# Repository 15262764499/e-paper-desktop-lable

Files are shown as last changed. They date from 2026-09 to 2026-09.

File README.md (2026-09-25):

# 四色墨水屏桌面信息终端

基于 STM32G070CBT6 与 4.2 英寸 400 × 300 四色墨水屏的桌面终端。设备通过 NFC 识别与配对，通过 BLE 接收手机或电脑制作的画面；也可以显示带本地时钟和环境信息的日历，并用七颗 LED 呈现灯效。仓库提供设备固件、Bootloader、硬件资料、3D 外壳模型及客户端对接文档。

> 本仓库目前主要是设备端工程和协议资料。Android 与 Windows 应用的源码、安装包及各自的构建说明未包含在当前仓库中；下文“二次开发”列出的是开发这两端应用时需要阅读的设备协议与需求文档。部分文档保留早期设计草案和历史验证记录，遇到不一致时请结合当前固件接口核对。

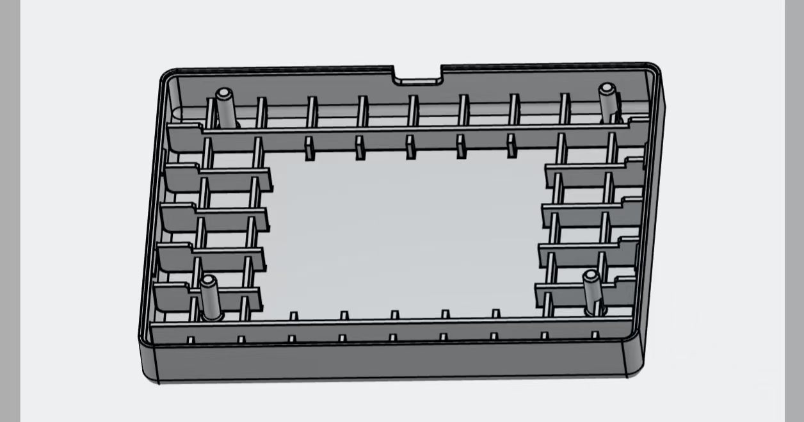
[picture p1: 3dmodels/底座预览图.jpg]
底座预览

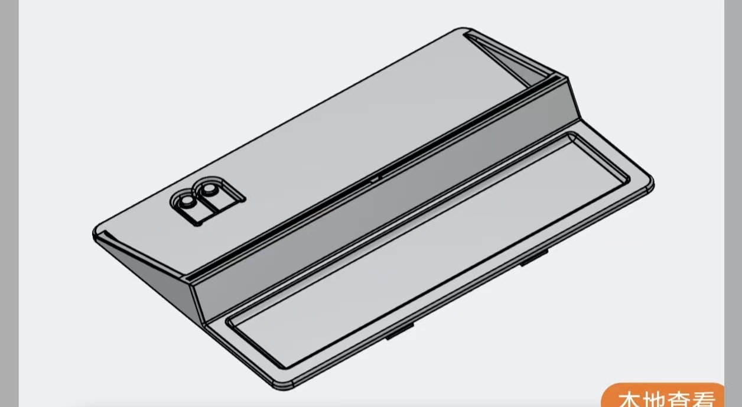
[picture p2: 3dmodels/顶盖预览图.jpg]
顶盖预览


## 能做什么

- **四色图片显示**：客户端将照片裁剪并缩放到 400 × 300，量化为黑、白、黄、红四种颜色，编码为 30,000 字节的 2bpp 画面，经 BLE 分包发送；设备完成校验后刷新。墨水屏断电仍能保持最后画面。
- **NFC 配对与 BLE 通信**：手机通过 ST25DV04K 的 NDEF 信息取得设备身份与配对凭据，再连接 CH9140；图片、控制命令和升级数据经 BLE 传送，NFC 不承担图片传输。
- **日历与温湿度**：客户端制作日历底图，STM32 使用 RTC 和 AHT20 叠加日期、今日高亮及室内温度；保存的底图支持设备在跨日后本地重绘。Android 日历方案还包含系统日历事件、手机定位与室外天气。
- **七灯效果**：74HC595 驱动七颗 LED，提供关闭、湿度呼吸、由中心向两侧展开的扩散呼吸三种模式；NFC 感应时临时显示同步呼吸。按键和经过认证的 BLE 命令可选择背景模式。
- **BLE 固件升级**：Bootloader 接收 .epota 升级包，校验后更新 Application；中断升级时可以重新进入恢复传输流程。
- **电脑串口灯效**：设备经 CH340 的 USART1 接收 Pulse v1 控制协议，可将电脑端的负载数据映射为 LED 效果。该路径与通过 CH9140 使用 BLE 发送画面的路径不同。

## 硬件与通信

| 模块 | 用途 |
| --- | --- |
| STM32G070CBT6 | 固件运行、墨水屏刷新、RTC、协议处理和灯效控制 |
| GDEM042F86，400 × 300 四色墨水屏 | 图片与日历显示 |
| ST25DV04K | NFC 近场识别与配对信息 |
| CH9140 | BLE 透明串口，连接 MCU 的 USART2 |
| AHT20 | 室内温湿度采样 |
| 74HC595、七颗 LED | 氛围灯输出 |
| CH340 | 电脑与 MCU 的 USART1 串口通信 |

具体接线请看 [电路图](refer_doc/SCH_Schematic3_2026-09-11.pdf) 与 [CubeMX 配置](refer_doc/墨水屏项目.ioc)。三维模型和预览图位于 [3dmodels](3d外壳)；立创 EDA 工程位于 [pcbproject](pcbproject)。

## 仓库导航

```text
Core/          STM32 Application：屏幕、传图、RTC、日历、传感器、灯效和串口协议
Bootloader/    BLE OTA Bootloader
Drivers/       STM32 HAL / CMSIS 依赖
files/         硬件、Android 需求和设备通信协议文档
docs/          Windows 固件构建说明及 Pulse 开发记录
3d外壳/        外壳 STEP 模型、Blender 文件与预览图
pcbproject/    PCB 工程
tools/         OTA 打包等辅助工具
tests/         设备端协议和灯效测试
```

## 二次开发：先读哪些文档

### Android 应用

建议按以下顺序阅读。文档路径均在 files/ 内：

1. [ANDROID_APP_REQUIREMENTS.md](refer_doc/ANDROID_APP_REQUIREMENTS.md)：应用流程、NFC 唤起、BLE GATT、认证、图片处理、传输状态与错误处理的总入口。
2. [IMAGE_TRANSFER_PROTOCOL.md](refer_doc/IMAGE_TRANSFER_PROTOCOL.md)：NDEF 格式、BLE 帧、HELLO/认证、2bpp 数据、分包 ACK、CRC/HMAC 和状态码。客户端与固件联调以此为基础。
3. [ANDROID_CALENDAR_DEVELOPMENT.md](refer_doc/ANDROID_CALENDAR_DEVELOPMENT.md)：若开发日历功能，阅读日历底图与 MCU 叠加层的分工、系统日历、天气、时间同步和画布坐标。文档含早期草案描述，实际支持情况还需与当前固件核对。
4. [ANDROID_LED_CONTROL.md](refer_doc/ANDROID_LED_CONTROL.md)：若开发七灯控制或动画预览，阅读三种模式、颜色、BLE 命令与 NFC 临时效果的优先级。
5. [BLE_OTA_DESIGN.md](refer_doc/BLE_OTA_DESIGN.md)：若开发手机端固件升级，阅读进入 Bootloader、重新连接、.epota 包结构、升级分片和恢复流程。

### Windows / 电脑端应用

电脑端涉及两条通信路径，先确定要开发哪一项：

| 功能 | files/ 中应读的文档 | 还应核对 |
| --- | --- | --- |
| BLE 传图与设备控制 | [IMAGE_TRANSFER_PROTOCOL.md](refer_doc/IMAGE_TRANSFER_PROTOCOL.md)；日历功能参考 [ANDROID_CALENDAR_DEVELOPMENT.md](refer_doc/ANDROID_CALENDAR_DEVELOPMENT.md)，灯效参考 [ANDROID_LED_CONTROL.md](refer_doc/ANDROID_LED_CONTROL.md) | Android 专属的 NFC 唤起、系统日历、定位和权限部分需要替换为 Windows 实现；电脑端同样要满足设备认证与报文格式 |
| BLE 固件升级 | [BLE_OTA_DESIGN.md](refer_doc/BLE_OTA_DESIGN.md) 和 [IMAGE_TRANSFER_PROTOCOL.md](refer_doc/IMAGE_TRANSFER_PROTOCOL.md) | BLE 断开重连、升级清单与 ACK/状态处理 |
| CH340 串口 Pulse 灯效 | files/ 内无独立的 Pulse 协议文档；LED 背景逻辑可读 [LED_LOGIC.md](refer_doc/LED_LOGIC.md) | [MCU_BUILD_WINDOWS.md](refer_doc/MCU_BUILD_WINDOWS.md)、[Pulse Windows 设计记录](refer_doc/superpowers/plans/2026-09-16-pulse-windows.md)、`Core/Inc/pulse_protocol.h`、`Core/Src/pulse_protocol.c`、`Core/Src/pulse_uart.c` |

### 设备固件、硬件与外壳

- 修改设备端协议或屏幕驱动：先读 [图片传输协议](refer_doc/IMAGE_TRANSFER_PROTOCOL.md)，再看 `Core/Src/image_transfer.c`、`Core/Src/gdem042f86.c`。
- 修改 OTA：先读 [OTA 设计]（refer_doc/BLE_OTA_DESIGN.md)，再看 `Bootloader/` 和 `tools/package_ota.py`。
- 修改灯效、按键或传感器：阅读 [LED_LOGIC.md](refer_doc/LED_LOGIC.md) 和 [ANDROID_LED_CONTROL.md](files/ANDROID_LED_CONTROL.md)，再看 `Core/Src/led_595.c`、`Core/Src/aht20.c`。
- 修改硬件与外壳：参考 [原理图](refer_doc/SCH_Schematic3_2026-09-11.pdf)、[IOC](files/墨水屏项目.ioc)、[PCB 工程](pcbproject) 和 [外壳模型](3d外壳)。[HARDWARE_2026_09_11.md](refer_doc/HARDWARE_2026_09_11.md) 是历史适配记录，其中早期同步呼吸演示已由当前三模式逻辑替代。

## 编译与烧录设备固件

在具备 Arm GNU Toolchain 与 Make 的环境中，从仓库根目录编译：

```bash
make -j4 firmware
```

Windows PowerShell 可使用仓库内脚本；工具链安装与定位方法见 [Windows 构建说明](refer_doc/MCU_BUILD_WINDOWS.md)：

```powershell
powershell -NoProfile -ExecutionPolicy Bypass -File .\build-mcu.ps1
```

| 组件 | 输出 HEX | BIN 烧录起始地址 |
| --- | --- | --- |
| Bootloader | `build_bootloader/epaper_bootloader.hex` | `0x08000000` |
| Application | `build/epaper_project.hex` | `0x08006000` |

HEX 自带目标地址；首次在空白芯片上使用时需分别写入 Bootloader 和 Application。Application 的 BIN 不能烧到 `0x08000000`。已有设备更新前请先阅读 [OTA 布局与恢复说明](refer_doc/BLE_OTA_DESIGN.md)，避免误擦 Bootloader、日历底图或 OTA 元数据。

## 协议与数据提示

- BLE 传图使用 `FFF0` 服务、`FFF1` Notify、`FFF2` Write；底层串口为 115200、8N1。图片画面固定 400 × 300、2bpp、30,000 字节；图片传输需要逐块确认并在校验完成后等待屏幕刷新。
- NFC 配对数据包含设备标识与密钥信息。不要在日志、演示截图或 issue 中公开真实设备的配对凭据。
- 仓库中的 OTA 发布密钥仅供开发测试；若用于实际交付设备，应替换并妥善保管发布凭据。具体限制见 [OTA 安全边界](refer_doc/BLE_OTA_DESIGN.md)。

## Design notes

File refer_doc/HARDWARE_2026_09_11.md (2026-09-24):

# 2026-09-11 硬件适配与呼吸灯测试

> 以下为 2026-09-11 历史硬件演示记录。当前三模式驱动、接口和时序以 [LED_LOGIC.md](LED_LOGIC.md) 与 [ANDROID_LED_CONTROL.md](ANDROID_LED_CONTROL.md) 为准；旧 SetMask/共用 OE PWM 演示已替换。

固件按 `SCH_Schematic3_2026-09-11.pdf` 接线适配。

| MCU 引脚 | 功能 | 74HC595 引脚 |
| --- | --- | --- |
| PA4 / AF1 | SPI2_MOSI | DS，14 脚 |
| PA0 / AF0 | SPI2_SCK | SHCP，11 脚 |
| PB14 / GPIO | 锁存脉冲 | STCP，12 脚 |
| PA8 / AF2 | TIM1_CH1，低有效 PWM | OE#，13 脚 |

SPI2 使用模式 0、MSB 优先、8 位、单线发送；当前 16 MHz 时钟下速率为 500 kbit/s。引脚复用依据 [ST 数据手册表 12](https://www.st.com/resource/en/datasheet/stm32g070cb.pdf)。MR# 由图中的 R70 上拉。

图中实际是 Q1～Q7 接 7 颗 LED，Q0（15 脚）未连接；Q7S 是级联输出，不是第八路灯。LED 阳极通过 1 kΩ 接 3V3_SYS，阴极接 Q 输出，因此输出低电平点亮。初始化移入 `0x01`，让 Q1～Q7 有效、Q0 关闭。

上电进入循环同步呼吸：1.5 秒渐亮、1.5 秒渐暗。PWM 为 1 kHz，亮度每 10 ms 更新，使用平方曲线改善暗部变化。SysTick 只计算亮度并写 CCR1，不进行 SPI 传输或延时；正常中断开启时，墨水屏阻塞等待不会停止呼吸。Flash 擦写或关闭中断仍可能使亮度更新短暂停顿。

`Core/Inc/led_595.h` 中的 `LED595_BREATH_PERIOD_MS` 可修改周期，`LED595_DEMO_MASK` 可选择输出。掩码的 bit0～bit7 对应 Q0～Q7，1 表示选中；若以后补接 Q0 的 LED，可改为 `0xFF`。`LED595_SetMask()` 应从主循环调用，支持后续流水灯效果；当前演示为同步呼吸。

NFC、BLE、AHT20 与 I2C 上拉均按直供电处理，代码不再配置 PB9、PB10、PB5 为电源使能。NFC 直接探测 I2C 地址，不再切换电源极性。BLE 使用 PB15：`Bluetooth_Sleep()` 拉低 SLP，`Bluetooth_Wake()` 拉高并等待 500 ms。休眠前需结束 BLE 收发；当前传图程序默认唤醒，不自动空闲休眠，以便手机继续连接。独立墨水屏诊断演示中的原断电操作已改为 SLP 休眠。Bootloader 在 OTA 期间保持 BLE 唤醒，并把 PA8 拉高关闭灯输出。

构建：`make -j4 firmware`。

本次应用和 Bootloader 已编译、链接成功，Flash 的 text+data 分别为 36224 B / 72 KiB 和 11160 B / 24 KiB。链接器报告了 newlib 的 `_read/_write/_close/_lseek` 占位实现以及 RWX LOAD 段警告；本次未调整系统调用或链接脚本。尚未烧录或进行实物测试。

- 应用：`build/epaper_project.hex`；BIN 加载地址为 `0x08006000`。
- Bootloader：`build_bootloader/epaper_bootloader.hex`；BIN 加载地址为 `0x08000000`。
- HEX 自带地址。应用依赖本项目 Bootloader，不应将应用 BIN 写到 Flash 起始地址。

`files/墨水屏项目.ioc` 已同步删除旧电源引脚并加入 SPI2/TIM1/PB14 配置。呼吸灯逻辑和初始化由 `led_595.c` 管理；本次没有运行 CubeMX 重新生成工程。以后重新生成时需保留 `LED595_Init()`、SysTick 中的 `LED595_Tick()` 和 Makefile 源文件项。

板上检查：上电观察 7 颗灯同步呼吸；示波器检查 PA0 的 8 个时钟及其后的 PB14 锁存上升沿，PA8 应为低有效 1 kHz PWM。随后验证手机连接、NFC 配对、传图和 OTA。编译与静态检查无法代替上述实物验证。

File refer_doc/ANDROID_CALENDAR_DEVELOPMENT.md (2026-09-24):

# 安卓端日历功能开发说明

版本：0.1（联调草案）  
目标硬件：STM32G070CBT6 + CH9140 + ST25DV04K + AHT20 + GDEM042F86 400×300 四色墨水屏  
依赖协议：[IMAGE_TRANSFER_PROTOCOL.md](IMAGE_TRANSFER_PROTOCOL.md)

## 1. 目标

安卓应用在用户触碰 NFC 后完成以下流程：

1. 读取 NFC 配对信息并连接 CH9140 BLE。
2. 与 STM32 完成 `HELLO/AUTH` 身份认证。
3. 接收 STM32 上传的 AHT20 室内温湿度。
4. 使用手机时间校准 STM32 RTC。
5. 读取 Android 系统日历中今天的日程事件。
6. 申请前台定位权限，获取手机当前位置，并通过项目默认天气提供商 Open-Meteo 获取室外天气。
7. 绘制 400×300 日历基础画面，包括日历框、星期标题、天气和今日日程。
8. 将基础画面量化、打包并通过现有安全图片协议发送。
9. STM32 在基础画面上叠加日期数字、当前日期、室内温度和今日高亮框，再刷新墨水屏。
10. 手机不再连接时，STM32 依靠 RTC 在跨日后重新绘制日期、室内温度和高亮框。

本文中的“今日任务”默认指 Android `Calendar Provider` 中的日历事件，不包括 Google Tasks、Microsoft To Do 等独立待办服务。若产品需要真正的待办事项，需要另外接入对应账号和网络 API。

## 2. 两端职责

| 内容 | 安卓端 | STM32端 |
|---|---|---|
| 400×300基础画面 | 生成并发送 | 接收并保存日历模板 |
| 固定日历框 | 绘制 | 不绘制 |
| 星期标题 | 绘制 | 不绘制 |
| 室外天气和图标 | 获取、绘制 | 不解析天气 |
| 今日系统日历事件 | 读取、排版、绘制 | 不保存事件文本 |
| 月份日期数字1～31 | 预览时模拟，传输画面中留白 | 根据RTC绘制 |
| 当前年月日 | 预览时模拟，传输画面中留白 | 根据RTC绘制 |
| 今日高亮框 | 预览时模拟，传输画面中留白 | 根据RTC绘制 |
| 室内温度 | 用于最终预览 | 从AHT20读取并绘制 |
| 时间维护和跨日 | 发送校时数据 | RTC维护并在零点刷新 |

安卓发送的是“基础模板”，不是最终画面。安卓预览必须在基础模板的副本上模拟 STM32 叠加层，不能把叠加层写进实际发送的30,000字节，否则会出现日期和高亮重复。

## 3. 必须解决的模板保存问题

当前固件把图片直接写入墨水屏控制器RAM，不在STM32中保存。屏幕断电后，STM32第二天无法重新得到安卓绘制的天气和任务底图。

日历模式需要嵌入式端新增一个保留Flash区域：

- 建议保留最后32KB内部Flash。
- 保存30,000字节安卓日历基础模板及少量元数据。
- 普通照片仍然不保存。
- 模板只有在长度、CRC32和HMAC全部验证成功后才标记为有效。
- 收到相同CRC的模板时不重复擦写Flash。
- 固件升级可以擦除模板；升级后等待用户再次碰NFC生成即可。

当前固件约使用25KB Flash，STM32总Flash为128KB，预留32KB模板区后仍有明显余量。链接脚本必须缩小应用Flash长度，避免程序覆盖模板区。

如果不增加模板存储，STM32只能在手机连接当天叠加字符，无法在第二天保留安卓绘制的天气和任务区域后再进行完整刷新。

## 4. 固定画布和布局版本

所有绘图使用固定的400×300逻辑像素，不使用Android的`dp`、屏幕密度或自动缩放。

布局版本：`CALENDAR_LAYOUT_V1 = 1`

### 4.1 区域定义

| 区域 | 坐标 | 所有者 | 内容 |
|---|---|---|---|
| 日期标题 | `x=0..175, y=0..47` | STM32 | `2026年8月20日`等 |
| 室内温度 | `x=176..279, y=0..47` | STM32 | `室内 25.6℃` |
| 星期标题 | `x=0..279, y=48..71` | 安卓 | 一、二、三、四、五、六、日 |
| 月历网格 | `x=0..279, y=72..299` | 安卓+STM32 | 安卓画线；STM32画日期和高亮 |
| 室外天气 | `x=280..399, y=0..115` | 安卓 | 天气、室外温度、天气图标 |
| 今日日程 | `x=280..399, y=116..299` | 安卓 | 系统日历事件 |

屏幕右侧和左侧之间在 `x=279` 处绘制黑色分隔线。

### 4.2 月历网格

- 月历宽度280像素，每列40像素。
- 星期标题高度24像素。
- 日期区固定6行，每行38像素。
- 竖线位置：`0, 40, 80, 120, 160, 200, 240, 279`。
- 横线位置：`48, 72, 110, 148, 186, 224, 262, 299`。
- STM32根据当月1日星期和当月天数确定每个日期所在单元格。
- STM32将日期数字放在单元格左上角，建议偏移 `(4, 3)`。
- 今日高亮框在单元格边界内缩2像素，建议使用红色2像素描边。
- 周六、周日日期可以使用红色，工作日使用黑色。

### 4.3 安卓必须留白的区域

基础模板中以下位置必须保持纯白色 `#FFFFFF`，不能绘制文字、图标或抖动噪声：

- 日期标题区域内部。
- 室内温度区域内部。
- 所有日期单元格内部，网格线除外。
- 今日高亮框可能经过的单元格内缩0～4像素区域。

否则STM32叠加字符时无法可靠清除旧日期和旧高亮框。

## 5. NFC、BLE和传输流程

```text
NFC碰一碰
  -> BLE扫描和连接
  -> 订阅FFF1
  -> HELLO_REQ / HELLO_RSP
  -> AUTH_PROVE
  -> SENSOR_RSP（室内温湿度）
  -> TIME_SYNC（新增）
  -> 查询今天的系统日历
  -> 获取或读取缓存天气
  -> 生成日历基础模板和最终预览
  -> IMAGE_BEGIN（日历模式）
  -> IMAGE_DATA
  -> IMAGE_END
  -> 等待COMPLETE
```

传输仍沿用现有分包、CRC32、ACK、重试和图片HMAC规则。日历模板仍然必须恰好是30,000字节。

## 6. 协议扩展要求

本节需要安卓和固件同步实现；当前固件尚未支持这些扩展。

### 6.1 能力声明

建议在`HELLO_RSP`末尾增加两字节`capabilities`：

```text
bit0 = 支持日历基础模板
bit1 = 支持TIME_SYNC
bit2 = 支持RTC自动跨日刷新
bit3 = 支持内部Flash模板保存
```

安卓只有在必要能力全部存在时才显示“发送日历”。旧固件仍可继续使用普通照片模式。

### 6.2 TIME_SYNC

建议新增：

```text
TIME_SYNC = 0x04
```

payload：

| 偏移 | 长度 | 内容 |
|---:|---:|---|
| 0 | 8 | Unix epoch seconds，u64小端 |
| 8 | 2 | 当前UTC偏移分钟数，i16小端；中国为480 |
| 10 | 16 | timeTag |

认证标签：

```text
timeTag = first16(HMAC-SHA256(
  sessionKey,
  ASCII("EPD-TIME-V1") ||
  sequenceLE16 || epochSecondsLE64 || utcOffsetMinutesLE16
))
```

STM32验证成功后设置RTC并返回普通`ACK`。安卓应在生成日历前发送校时，设备拒绝校时时不得发送日历模板。

### 6.3 日历渲染配置

现有`IMAGE_BEGIN`偏移9的`reserved`改为`renderProfile`：

```text
0x00 = 普通图片，不叠加、不保存
0x11 = 日历布局V1，叠加日期/室内温度/高亮并保存模板
```

普通图片继续使用原有`EPD-IMAGE-V1`标签。日历模式使用独立域，防止渲染配置被未授权修改：

```text
calendarTag = first16(HMAC-SHA256(
  sessionKey,
  ASCII("EPD-CALENDAR-V1") ||
  imageIdLE32 || sizeLE32 || imageCrcLE32 ||
  renderProfile || frameBytes
))
```

`IMAGE_END`结构可以保持不变，但日历模式下最后16字节应填`calendarTag`。

## 7. AHT20室内温湿度

当前协议已经定义：

```text
SENSOR_REQ = 0x03
SENSOR_RSP = 0x84
```

认证成功后STM32会主动发送一次`SENSOR_RSP`。安卓需要验证传感器HMAC后再使用数据。

应用数据模型：

```kotlin
data class IndoorReading(
    val temperatureCentiC: Int,
    val humidityCentiPercent: UInt,
    val receivedAt: Instant,
    val valid: Boolean,
)
```

显示格式：

- 室内温度保留一位小数，例如`25.6℃`。
- 湿度本版本不由STM32叠加，可以保留在安卓预览或以后扩展。
- `SENSOR_RSP`失败时，最终预览显示`室内 --.-℃`。
- STM32本地跨日刷新时重新读取AHT20，使用最新温度，不依赖安卓预览值。
- 日历模式下STM32每5分钟重新读取一次AHT20，并在顶部同时显示室内温度和湿度；该周期刷新不会在普通照片模式下执行。

## 8. 读取Android系统日历

Android官方`Calendar Provider`通过`CalendarContract`提供日历事件。读取需要危险权限`READ_CALENDAR`；只读取事件不需要`WRITE_CALENDAR`。

官方参考：

- [Calendar Provider概览](https://developer.android.com/identity/providers/calendar-provider)
- [CalendarContract.Instances](https://developer.android.com/reference/android/provider/CalendarContract.Instances)
- [READ_CALENDAR权限](https://developer.android.com/reference/android/Manifest.permission#READ_CALENDAR)

### 8.1 Manifest

```xml
<uses-permission android:name="android.permission.READ_CALENDAR" />
```

运行时使用`ActivityResultContracts.RequestPermission()`申请。用户拒绝后仍允许生成日历，只在任务区域显示“未授权读取日历”，不要重复强制弹窗。

### 8.2 为什么查询Instances

应查询`CalendarContract.Instances`，不要直接只查`Events`：

- `Instances`会展开重复事件的每一次发生记录。
- 可以正确得到今天实际发生的实例。
- 查询URI必须附加开始和结束毫秒时间戳。

### 8.3 今天的时间窗口

必须根据手机当前时区计算本地自然日，不能简单使用`now ± 24小时`：

```kotlin
val zone = ZoneId.systemDefault()
val today = LocalDate.now(zone)
val beginMillis = today
    .atStartOfDay(zone)
    .toInstant()
    .toEpochMilli()
val endMillis = today
    .plusDays(1)
    .atStartOfDay(zone)
    .toInstant()
    .toEpochMilli()
```

### 8.4 查询示例

```kotlin
data class TodayEvent(
    val eventId: Long,
    val title: String,
    val beginMillis: Long,
    val endMillis: Long,
    val allDay: Boolean,
    val location: String?,
)

fun queryTodayEvents(
    resolver: ContentResolver,
    beginMillis: Long,
    endMillis: Long,
): List<TodayEvent> {
    val uriBuilder = CalendarContract.Instances.CONTENT_URI.buildUpon()
    ContentUris.appendId(uriBuilder, beginMillis)
    ContentUris.appendId(uriBuilder, endMillis)

    val projection = arrayOf(
        CalendarContract.Instances.EVENT_ID,
        CalendarContract.Instances.TITLE,
        CalendarContract.Instances.BEGIN,
        CalendarContract.Instances.END,
        CalendarContract.Instances.ALL_DAY,
        CalendarContract.Instances.EVENT_LOCATION,
        CalendarContract.Instances.STATUS,
    )

    val result = mutableListOf<TodayEvent>()
    resolver.query(
        uriBuilder.build(),
        projection,
        null,
        null,
        "${CalendarContract.Instances.BEGIN} ASC",
    )?.use { cursor ->
        val eventIdIndex = cursor.getColumnIndexOrThrow(
            CalendarContract.Instances.EVENT_ID)
        val titleIndex = cursor.getColumnIndexOrThrow(
            CalendarContract.Instances.TITLE)
        val beginIndex = cursor.getColumnIndexOrThrow(
            CalendarContract.Instances.BEGIN)
        val endIndex = cursor.getColumnIndexOrThrow(
            CalendarContract.Instances.END)
        val allDayIndex = cursor.getColumnIndexOrThrow(
            CalendarContract.Instances.ALL_DAY)
        val locationIndex = cursor.getColumnIndexOrThrow(
            CalendarContract.Instances.EVENT_LOCATION)
        val statusIndex = cursor.getColumnIndexOrThrow(
            CalendarContract.Instances.STATUS)

        while (cursor.moveToNext()) {
            if (cursor.getInt(statusIndex) ==
                CalendarContract.Events.STATUS_CANCELED) {
                continue
            }

            result += TodayEvent(
                eventId = cursor.getLong(eventIdIndex),
                title = cursor.getString(titleIndex)
                    ?.trim()
                    ?.takeIf { it.isNotEmpty() }
                    ?: "未命名日程",
                beginMillis = cursor.getLong(beginIndex),
                endMillis = cursor.getLong(endIndex),
                allDay = cursor.getInt(allDayIndex) != 0,
                location = cursor.getString(locationIndex)
                    ?.trim()
                    ?.takeIf { it.isNotEmpty() },
            )
        }
    }
    return result
}
```

实际调用前必须再次检查`READ_CALENDAR`权限，并在`Dispatchers.IO`执行查询。

### 8.5 任务排版规则

- 标题固定为“今日日程”。
- 全天事件显示`全天 标题`。
- 普通事件显示`HH:mm 标题`。
- 按开始时间升序排列。
- 最多显示5条。
- 标题最多两行，超出区域使用省略号。
- 超过5条时，最后一行显示`另有 N 项`。
- 不显示事件描述、参会人、会议链接和账号邮箱。
- 日志中不得输出事件标题和地点。

## 9. 跨日后的任务和天气过期

STM32能够自主更新日期和室内温度，但安卓绘制的任务和天气不会自动变化。

日历模板元数据至少保存：

```text
templateLocalDate
weatherValidUntilEpoch
templateCrc32
layoutVersion
```

推荐降级规则：

- RTC日期仍等于`templateLocalDate`：正常显示任务。
- RTC日期已经变化：STM32在重新流式输出模板时将任务区域覆盖为白色，并显示红色`SYNC`提示。
- 天气超过`weatherValidUntilEpoch`：将天气区域覆盖为白色并显示`SYNC`。
- 用户再次碰NFC后，安卓重新读取当天事件和天气并发送新模板。

如果希望跨日后仍显示正确任务，协议必须改为安卓发送未来多天的结构化事件，由STM32负责文字排版；这不属于本版本范围。

## 10. 定位和天气数据要求

Android系统没有统一的“系统默认天气服务”API。本项目指定
[Open-Meteo Forecast API](https://open-meteo.com/en/docs)作为默认天气提供商，
但仍通过接口隔离，方便以后替换服务商。

天气只在用户通过NFC进入日历生成流程、应用处于前台时获取一次位置，不持续跟踪，也不申请后台定位权限。城市级天气不要求GPS级精度；用户只授予近似位置时也必须正常工作。

### 10.1 Manifest权限

```xml
<uses-permission android:name="android.permission.INTERNET" />
<uses-permission android:name="android.permission.ACCESS_COARSE_LOCATION" />
<uses-permission android:name="android.permission.ACCESS_FINE_LOCATION" />
```

不要声明：

```xml
<uses-permission android:name="android.permission.ACCESS_BACKGROUND_LOCATION" />
```

Android 12及以上允许用户只授予近似位置。若应用请求精确位置，必须把`ACCESS_FINE_LOCATION`和`ACCESS_COARSE_LOCATION`放在同一次运行时请求中；应用不能把“仅授予近似位置”视为错误。参考Android官方的[运行时定位权限说明](https://developer.android.com/develop/sensors-and-location/location/permissions/runtime)。

```kotlin
val locationPermissionLauncher = registerForActivityResult(
    ActivityResultContracts.RequestMultiplePermissions()
) { result ->
    when {
        result[Manifest.permission.ACCESS_FINE_LOCATION] == true -> {
            loadWeather(LocationAccuracy.PRECISE)
        }
        result[Manifest.permission.ACCESS_COARSE_LOCATION] == true -> {
            loadWeather(LocationAccuracy.APPROXIMATE)
        }
        else -> {
            loadCachedWeatherOrUnavailable()
        }
    }
}

locationPermissionLauncher.launch(
    arrayOf(
        Manifest.permission.ACCESS_FINE_LOCATION,
        Manifest.permission.ACCESS_COARSE_LOCATION,
    )
)
```

权限应在用户点击“生成日历”或NFC识别成功后、界面说明天气需要当前位置时申请，不能在应用无上下文启动时直接弹出。

### 10.2 获取一次当前位置

推荐使用Google Play services的`FusedLocationProviderClient`：

```kotlin
interface DeviceLocationRepository {
    suspend fun getCurrentLocation(): Result<DeviceLocation>
}

data class DeviceLocation(
    val latitude: Double,
    val longitude: Double,
    val accuracyMeters: Float?,
    val capturedAt: Instant,
)
```

获取策略：

1. 权限已经授予后调用`getCurrentLocation()`请求一次新位置。
2. 使用平衡功耗精度，天气不要求高精度GPS。
3. 新位置超时或返回`null`时尝试`lastLocation`。
4. 最近位置不得早于6小时；超过6小时视为不可用。
5. 定位完成后不注册持续位置更新。
6. 系统定位关闭时提示用户打开定位，或者使用天气缓存。

Android官方建议需要较新鲜的位置时优先使用`getCurrentLocation()`，而`lastLocation`速度快但可能过期：[获取当前位置](https://developer.android.com/develop/sensors-and-location/location/retrieve-current)。

### 10.3 Open-Meteo请求

默认请求：

```text
GET https://api.open-meteo.com/v1/forecast
  ?latitude={latitude}
  &longitude={longitude}
  &current=temperature_2m,weather_code
  &daily=temperature_2m_max,temperature_2m_min,precipitation_probability_max
  &timezone=auto
  &forecast_days=2
```

应用只需要当前天气和当天预报：

- `current.temperature_2m`：室外当前温度。
- `current.weather_code`：WMO天气代码，用于选择四色图标和中文描述。
- `daily.temperature_2m_min[0]`：当天最低温。
- `daily.temperature_2m_max[0]`：当天最高温。
- `daily.precipitation_probability_max[0]`：当天最大降水概率。
- `timezone=auto`：让天气结果使用坐标对应时区。

经纬度发送前建议四舍五入到小数点后两位，约为公里级精度，足以查询天气并减少不必要的位置精度暴露。

### 10.4 数据接口

```kotlin
data class WeatherSnapshot(
    val conditionText: String,
    val currentCentiC: Int,
    val lowCentiC: Int?,
    val highCentiC: Int?,
    val precipitationPercent: Int?,
    val icon: WeatherIcon,
    val observedAt: Instant,
    val validUntil: Instant,
)

interface WeatherRepository {
    suspend fun getWeather(
        location: DeviceLocation,
        forceRefresh: Boolean,
    ): Result<WeatherSnapshot>
}
```

要求：

- 默认使用Open-Meteo，不在UI中要求用户选择天气提供商。
- 必须同时支持精确位置和近似位置授权结果。
- 不申请后台定位，应用离开前台后不继续更新位置。
- API失败时优先使用未过期缓存。
- 没有可用缓存时显示“天气不可用”，仍允许发送日历。
- Open-Meteo服务条款、请求额度和商业使用条件需要在发布前复核；接口层必须允许以后切换自建代理或其他提供商。
- 明确区分“室外”天气温度和AHT20“室内”温度。
- 日志、崩溃报告和分析平台不得记录原始经纬度。

## 11. 安卓绘图实现

使用`Bitmap + Canvas + Paint`生成固定像素画面：

```kotlin
val bitmap = Bitmap.createBitmap(
    400,
    300,
    Bitmap.Config.ARGB_8888,
)
val canvas = Canvas(bitmap)
canvas.drawColor(Color.WHITE)
```

Android官方`Canvas`支持绘制文字、直线、矩形和Bitmap：
[Canvas API](https://developer.android.com/reference/android/graphics/Canvas)。

建议拆分：

```text
CalendarBaseRenderer
  drawGrid()
  drawWeekdayHeader()
  drawWeather()
  drawTodayEvents()
  drawSyncTimestamp()

CalendarPreviewOverlayRenderer
  drawDateNumbers()
  drawCurrentDateHeader()
  drawIndoorTemperature()
  drawTodayHighlight()
```

`CalendarBaseRenderer`的输出参与CRC/HMAC并发送；`CalendarPreviewOverlayRenderer`只作用于预览副本。

### 11.1 色板

| 色码 | 颜色 | RGB建议值 |
|---:|---|---|
| 0 | 黑 | `#000000` |
| 1 | 白 | `#FFFFFF` |
| 2 | 黄 | `#FFD700` |
| 3 | 红 | `#DC0000` |

日历UI模式关闭Floyd–Steinberg抖动，避免文字和细线产生噪点。天气照片类图标也应使用预先制作的四色图标。

### 11.2 字体

- MVP可以使用Android系统无衬线字体。
- 文字使用整数像素坐标。
- 网格、正文和图标在400×300原始尺寸上直接绘制，不先画大图再缩小。
- 若产品要求不同手机生成完全一致的字形，应打包经过授权的字体子集。
- 任务区域应按实际像素宽度测量和省略，不能按字符数量硬截断。

### 11.3 2bpp打包

基础模板最终量化为四色后按现有协议打包：

```text
byte = p0 << 6 | p1 << 4 | p2 << 2 | p3
```

- 每行100字节。
- 共300行。
- 总长度必须为30,000字节。
- `p0`是当前字节最左侧像素。

## 12. UI和状态

认证成功后的日历页面显示：

- 当前设备短ID。
- 室内温湿度读取状态。
- 系统日历权限状态。
- 定位权限及当前位置获取状态。
- 今天读取到的事件数量。
- 天气更新时间。
- 400×300最终模拟预览。
- “重新读取日程和天气”。
- “发送日历到墨水屏”。

发送按钮只有在以下条件满足时启用：

- BLE已认证。
- `TIME_SYNC`成功。
- 固件声明日历模板能力。
- 基础模板编码长度为30,000字节。
- 最终预览已经生成。

日历权限或天气失败不是致命错误，应用应显示对应占位内容后继续发送。

## 13. 建议代码模块

```text
calendar/
  CalendarPermissionController.kt
  SystemCalendarRepository.kt
  TodayEvent.kt
  CalendarLayoutV1.kt
  CalendarBaseRenderer.kt
  CalendarPreviewOverlayRenderer.kt

location/
  DeviceLocation.kt
  DeviceLocationRepository.kt
  FusedDeviceLocationRepository.kt

weather/
  WeatherRepository.kt
  OpenMeteoWeatherRepository.kt
  OpenMeteoWeatherApi.kt
  WeatherSnapshot.kt
  WeatherIconMapper.kt

device/
  IndoorReading.kt
  TimeSyncEncoder.kt
  CalendarTransferCoordinator.kt

image/
  FourColorQuantizer.kt
  FramePacker.kt

ui/calendar/
  CalendarScreen.kt
  CalendarViewModel.kt
  CalendarUiState.kt
```

耗时任务分配：

- 日历Provider查询：`Dispatchers.IO`。
- 单次前台定位：异步等待`FusedLocationProviderClient`结果。
- 天气网络请求：`Dispatchers.IO`。
- Canvas绘制、量化和打包：`Dispatchers.Default`。
- BLE GATT操作：沿用现有单写入队列，不能并发写。

## 14. 隐私和安全

- 只申请`READ_CALENDAR`，不要申请`WRITE_CALENDAR`。
- 定位仅用于天气查询；不申请后台定位权限，不持续跟踪。
- 向天气提供商发送前将坐标降低到约小数点后两位精度。
- 不持久化原始精确坐标，不在日志、崩溃报告或分析事件中记录坐标。
- 只查询当前自然日需要的事件实例。
- 不上传日历标题、地点或时间到天气服务。
- 不在日志、崩溃报告或分析事件中记录日历内容。
- 不缓存完整日历数据库；基础模板可以保留在内存直到传输完成。
- `TIME_SYNC`必须带会话HMAC，不能只依赖CRC32。
- 日历模板必须通过图片HMAC后才能被固件标记为有效。
- NFC pairing key和BLE session key继续遵循现有清理规则。

## 15. 验收测试

### 15.1 日历读取

- 无日历权限时能显示占位内容并继续发送。
- 普通事件、全天事件和重复事件都能显示。
- 已取消事件不显示。
- 跨越午夜和跨时区事件不会重复或遗漏。
- 事件超过5条时显示剩余数量。

### 15.2 绘图

- 输出严格为400×300和30,000字节。
- 网格线坐标与STM32日期坐标逐像素一致。
- 基础模板的日期、温度和高亮区域保持纯白。
- 最终预览不会把模拟叠加层写入发送数据。
- 文字和网格量化后没有灰色噪点。

### 15.3 定位和天气

- 精确位置授权时能够获取并显示天气。
- 仅授予近似位置时同样能够获取并显示天气。
- 拒绝定位权限时使用未过期缓存，否则显示“天气不可用”。
- 系统定位关闭、当前位置返回`null`和定位超时均不会导致应用崩溃。
- 请求中经纬度已降低精度，日志中不出现原始坐标。
- Open-Meteo超时、HTTP错误和字段缺失时能够降级。
- 应用进入后台后没有持续定位请求。

### 15.4 联调

- NFC、认证、传感器读取、校时和日历发送完整成功。
- 墨水屏显示的日期和手机本地日期一致。
- 室内温度来自AHT20，不是天气API。
- 今日高亮框落在正确星期列和周行。
- 手机断开后RTC跨日，STM32能自动移动高亮并更新日期。
- 跨日后旧任务区域按规则显示`SYNC`，不会继续冒充今日任务。
- 普通照片模式不写模板Flash，也不叠加任何日历字符。
- CRC或HMAC失败时模板不生效，设备不刷新未认证数据。

## 16. 当前待确认项

以下项目不阻塞安卓框架开发，文档采用了推荐默认值：

1. “今日任务”按系统日历事件实现；如果实际需要Google Tasks，需要新增独立需求。
2. 默认天气提供商确定为Open-Meteo，同时保留`WeatherRepository`抽象。
3. 天气使用一次前台定位；接受精确或近似位置，不申请后台定位。
4. 任务和天气跨日后由STM32遮盖并显示`SYNC`，等待下一次NFC同步。
5. 日历基础模板只保存一份，不保存历史图片。
6. 布局固定为本文的`CALENDAR_LAYOUT_V1`；任何坐标变化都必须递增布局版本并同步升级两端。

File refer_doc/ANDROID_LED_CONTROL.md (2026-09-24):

# 安卓三模式灯效控制与动画规范

版本：1.1，2026-09-14。对应本目录 STM32 固件，协议版本仍为 v1。
本文件是安卓端实现要求；当前仓库没有 Android App 源码，本文不代表 App 已完成开发。

本次修正：原“常亮”选项改称“扩散呼吸”，mode 值仍为 2、报文结构不变。安卓端需要更新周期为 3100 ms，移除旧的全亮时间饱和逻辑。

## 1. 三种模式

| mode | UI 名称 | 实物效果 |
|---:|---|---|
| 0 | 关闭 | 七灯全关，仍响应 NFC |
| 1 | 湿度呼吸 | 仅 Q2～Q6 显示湿度进度，顺序呼吸，80%RH 为满量程 |
| 2 | 扩散呼吸 | 从中心 Q4 向两端逐组渐亮，全亮保持 1 秒后一起渐暗熄灭，循环播放 |

按键循环：关闭 → 湿度呼吸 → 扩散呼吸 → 关闭。默认上电关闭，不写 Flash 保存。
NFC 是临时覆盖效果，不作为第四个可选模式：检测到手机射频场时七灯同步呼吸，离开后恢复所选模式。
NFC 期间实体按键忽略；安卓仍可选择背景模式，提示“已选择，移开手机后显示”。
重复设置相同模式不会重启动画，适合丢包重试。效果会自动循环；UI 本地“重播预览”仅用于从头演示，不要为预览反复控制实物。
背景动画时间在 NFC 覆盖期间继续推进，因此恢复扩散呼吸时继续当前周期，不强制从头展开。

## 2. 七灯顺序与颜色

UI 按 Q1、Q2、Q3、Q4、Q5、Q6、Q7 从左至右排列，中心是 Q4。
原理图能确认电气输出对应关系，PCB 实际观看方向需上板核对；如需镜像，仅调整布局映射，不改变协议中的 Q 编号。

| 输出 | 原理图灯编号 | 颜色 | UI sRGB 初值 | 最高 duty |
|---|---|---|---|---:|
| Q1 | LED4 | 绿（用户确认） | `#42E66C` | 80 |
| Q2 | LED7 | 绿（用户确认） | `#42E66C` | 80 |
| Q3 | LED8 / XL-1608UYC-06 | 黄 | `#FFD43B` | 100 |
| Q4 | LED9 / XL-1608UYC-06 | 黄 | `#FFD43B` | 100 |
| Q5 | LED11 / XL-1608UOC-04 | 橙 | `#FF8A32` | 100 |
| Q6 | LED6 / XL-1608UPC-06 | 粉红 | `#FF75B5` | 100 |
| Q7 | LED5 | 绿（用户确认） | `#42E66C` | 80 |

颜色类别依据：[黄色厂家资料](https://www.xinglight.cn/index.php?c=show&id=806)、[橙色厂家资料](https://www.xinglight.cn/uploadfile/202509/e93b12566642f7c.pdf)、[粉红色厂家资料](https://www.xinglight.cn/index.php?c=show&id=2681)。
RGB 是手机预览初值，不是灯珠色度测量值；后续按实物校色。绿色以用户指定为准。
这些是固定颜色单色灯，不能提供 RGB 调色控件。

## 3. BLE 接口

复用现有 `FFF2` Write / `FFF1` Notify、EP 帧、v1 版本、Sequence、CRC32 与 HELLO/AUTH 会话。
HELLO_RSP 的 capabilities 新增 bit5（`0x0020`）表示支持本规范，当前完整能力掩码为 `0x003F`。
未设置 bit5 的旧固件应显示“此固件不支持灯效控制”，禁止发送新命令。
已认证且传输状态为 AUTHENTICATED 才允许读写灯效；图片传输期间暂停灯效请求，避免占用发送队列。图片完成、取消、超时清除认证后重新 HELLO/AUTH。

### LED_SET，Type=0x05

payload 固定 17 字节：`mode(u8) | tag(16)`，mode 只能为 0、1、2。

```text
tag = first16(HMAC-SHA256(sessionKey,
  ASCII("EPD-LED-SET-V1") || sequenceLE16 || modeU8))
```

域字符串不含尾部 NUL。sessionKey 按主协议派生，是完整 32 字节。
成功仅回复 `LED_STATE (0x86)`，不另外发送成功 ACK；UI 收到同序号、CRC 和 HMAC 均正确的状态后才确认选中项。

### LED_GET，Type=0x06

payload 长度为 0。成功回复同序号 `LED_STATE`。
灯效页可每 500 ms 查询一次，收到回包后再发下一次；前台退出、断连和传图时暂停。没有主动推送，实体按键切换通过查询同步。
成功 SET/GET 会刷新认证空闲时间；查询停止较久后可能需要重新认证。

### LED_STATE，Type=0x86

payload 固定 35 字节，所有多字节整数均为小端：

| 偏移 | 长度 | 字段 |
|---:|---:|---|
| 0 | 1 | result，成功为 0 |
| 1 | 1 | selectedMode，0/1/2 |
| 2 | 1 | effectiveMode，0/1/2；3 表示 NFC 同步呼吸 |
| 3 | 1 | humidityValid，0/1 |
| 4 | 4 | humidityCentiPercent，单位 0.01%RH；无效为 `0xFFFFFFFF` |
| 8 | 4 | elapsedMs，当前有效效果的时间；湿度/NFC 为 0～2999，扩散呼吸为 0～3099，均循环 |
| 12 | 7 | dutyQ1～dutyQ7，单位百分比，按表中上限 |
| 19 | 16 | stateTag |

```text
stateTag = first16(HMAC-SHA256(sessionKey,
  ASCII("EPD-LED-STATE-V1") || sequenceLE16 || payload[0..18]))
```

这里 duty 是该时间点的软件目标占空比，用于预览核对，不是电流测量。
humidity 字段是灯效服务缓存，只有湿度模式且非 NFC 时约每 2 秒采样；不要用可能过期的 SENSOR_RSP 替代它驱动实际灯效预览。
错误沿用 ACK(0x82)：acknowledgedType=0x05/0x06，result 为 1 非法 mode、4 未认证、5 传输忙、6 长度错误、12 标签错误。出错不改变模式。
应用须按序号匹配响应、丢弃旧回包；失败保留上一次确认模式并提示重试，不把“已点击”显示成“设备已执行”。

## 4. 完整动画计算

固件采用整数计算，下面每一步 `floor` 都要保留；最后才转换为渲染用浮点数。
q 为 1～7；cap(q) 为绿色 80、其余 100；t 单位为 ms。

### NFC 临时效果：七灯同步呼吸

```text
p = t % 3000
r = min(p, 3000-p)
level = floor(r*r*100 / 2250000)
duty[q] = floor(level*cap(q)/100)
```

从暗到亮再到暗完整 3 秒，不使用闪烁或只播放亮起半程。手机射频短暂间歇由固件保持约 300 ms，App 以 effectiveMode 为准。

### 湿度模式：流水呼吸进度条

Q1/Q7 恒为 0，湿度无效或零时所有灯为 0。h 使用 0.01%RH 整数。
h≥8000 时 Q2～Q6 的 duty 直接等于各自 cap，保持亮起。
否则对 q=2～6：

```text
base = (q-2)*1600
fill = clamp(h-base, 0, 1600)
p = (t%3000 + 3000 - (q-2)*300) % 3000
level = 0
if fill>0 and p<1200:
    r = min(p, 1200-p)
    level = floor(floor(r*r*100/360000)*fill/1600)
duty[q] = floor(level*cap(q)/100)
```

每段代表 16%RH；相邻灯延后 300 ms，单灯亮暗过程 1200 ms，完整周期 3000 ms，包括尾部暗场。
末段不足 16%RH 时按 fill 缩放亮度。不要简单按灯数四舍五入，也不要让 Q1/Q7 参与湿度动画。

### 扩散呼吸模式：中心展开、保持 1 秒、渐暗循环

```text
p = t % 3100
delay = abs(q-4)*300
if p < 2500:
    r = clamp(p-delay, 0, 600)
else:
    r = 3100-p
level = floor(r*r*100/360000)
duty[q] = floor(level*cap(q)/100)
```

| 组 | 开始渐亮 | 达到最高亮度 |
|---|---:|---:|
| Q4 | 0 ms | 600 ms |
| Q3、Q5 | 300 ms | 900 ms |
| Q2、Q6 | 600 ms | 1200 ms |
| Q1、Q7 | 900 ms | 1500 ms |

组内两颗同步开始，灯珠颜色与上限各不相同。1500～2500 ms 全亮保持整整 1 秒；2500～3100 ms 七灯同步渐暗，到周期末全灭，然后从中心开始下一轮。完整周期 3100 ms，不添加额外暗场停顿。

## 5. UI 与同步

设备页新增“灯光”区域，含三个互斥选项、七灯预览、效果名称和连接状态。
使用七个固定位置的灯芯及对应颜色光晕，灯光归零时保留暗色轮廓，七颗灯始终完整可见。适配窄屏时等比缩小整组，不横向裁掉两端或裁掉光晕。另用文字标注颜色，方便色觉差异用户识别。

以显示帧时钟驱动渲染，建议 60 fps。不能每 500 ms 收到状态才切换灯亮度，否则动画会跳跃。
验证状态包后记录本机单调时间 `receivedAt` 和设备 `elapsedMs`，随后每帧计算：

```text
t = receivedElapsedMs + (monotonicNow - receivedAt)
if effectiveMode == 2: t = t%3100
else: t = t%3000
```

按有效模式和回包湿度使用上面的公式重建七路 duty。首帧可直接使用回包 duty，后续连续计算；每个有效回包重新校准时间基准。同一 effectiveMode 下避免因小幅网络抖动明显跳帧，可在 100 ms 内平滑校准，模式改变则立即切换。
这是含通信延迟的效果同步预览，不是光学级逐帧同步。无需把七路 PWM 每帧发回硬件。

渲染时 `intensity=duty/100f`，灯芯叠加和光晕强度随 intensity 连续变化；不要把绿色再除以 80 归一化成 100%，也不要对已经平方的 duty 再套平方曲线。暗轮廓不算点亮。
建议暗背景、原色灯芯、较淡的大范围光晕；不要用白色覆盖七灯而丢失对应颜色。

“设备实时”与“效果演示”必须分开标注：演示允许使用湿度滑杆、NFC 模拟开关和重播按钮，不向设备发送命令；实时预览采用设备状态，不用演示湿度冒充传感器值。
关闭模式也应有 NFC 覆盖动画。NFC 生效时显示“NFC 感应中 · 七灯呼吸”，所选模式仍保持高亮，说明离开后恢复。
断连后停止声称实时同步，保留“离线演示”入口。系统要求减少动画时提供静态示意/手动播放，但不擅自改变设备模式。

## 6. 安卓联调验收

- 三模式切换、SET 重试不重播、按键切换后 GET 同步；重连先读实际模式。
- 扩散呼吸在 0、300、600、900、1200、1500、2500、2800、3100、3400 ms 截帧：展开顺序正确，全亮保持 1 秒，随后同步渐暗至全灭，再开始下一轮；至少连续观察三个周期。
- 湿度 0、16、32、48、64、79.99、80、100%RH 以及无效样本；每种至少播放完整 3 秒；80% 以上持续亮起。
- NFC 在三种背景模式中均七灯同步亮暗；NFC 中安卓改模式不会打断覆盖，离开后恢复新模式。
- Q1/Q2/Q7 绿色、Q3/Q4 黄色、Q5 橙色、Q6 粉红；各自上限正确，不能显示成统一色。
- 七灯在窄屏、横屏和大字体下不裁切；模式名称、连接状态、错误反馈清楚。
- 错误 HMAC、非法 mode、未认证、传图忙、断连与旧固件能力缺失均正确处理。
- 与实物同时观察完整亮暗曲线，再按灯珠样品校准预览 RGB 和观看方向。

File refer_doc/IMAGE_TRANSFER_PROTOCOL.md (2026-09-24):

# NFC + BLE 墨水屏图片传输协议（v1）

## 1. 硬件链路

- NFC：ST25DV04K。手机只通过 NFC 取得目标设备 ID、协议版本和配对密钥。
- BLE：CH9140 透明串口，STM32 USART2 为 115200、8N1。
- BLE 服务：`FFF0`；手机订阅 `FFF1` Notify 接收 STM32 数据，向 `FFF2` Write 写入 STM32 数据。
- 屏幕：400×300、原生 2bpp，固定一帧 30,000 字节。
- 普通照片不写 Flash，按顺序直接写入屏控制器 RAM。日历模式会把一份已认证的 30,000 字节基础模板保存在 Flash 的 30 KiB 日历区，用于本地跨日重绘；最后 2 KiB 页面保留给 OTA 元数据。

## 2. NFC NDEF

NDEF 使用 MIME 类型 `application/vnd.epaper.pair`，payload 为：

| 偏移 | 长度 | 内容 |
|---:|---:|---|
| 0 | 4 | ASCII `EPD1` |
| 4 | 1 | 协议版本，当前为 `1` |
| 5 | 12 | STM32 96-bit UID，小端字节顺序，作为 board ID |
| 17 | 16 | 由固件根密钥和 STM32 UID 派生的本设备配对密钥 |
| 33 | 1 | flags；bit0=必须执行 HMAC 验证 |

安卓应用应声明该 MIME 的 NFC intent-filter。读取成功后保存 board ID 和密钥，再连接附近的 CH9140。此方案把“能够近距离读取 NFC”作为首次配对凭据；当前固件通过 UID 自动派生每台设备的不同密钥。量产时仍应保护根密钥，安全要求更高时应改用安全元件。

## 3. BLE 串口数据包

所有多字节整数均为小端：

| 字段 | 长度 | 说明 |
|---|---:|---|
| Magic | 2 | `45 50`（ASCII `EP`） |
| Version | 1 | `01` |
| Type | 1 | 消息类型 |
| Sequence | 2 | 安卓递增序号；响应复用请求序号 |
| Payload length | 2 | payload 字节数 |
| Payload | N | 最大 132 字节 |
| Packet CRC32 | 4 | IEEE CRC32，覆盖 Version 至 Payload，不覆盖 Magic |

CRC32 参数：poly `0xEDB88320`、初值 `0xFFFFFFFF`、最终异或 `0xFFFFFFFF`。

BLE 写入可能把一个包拆成多个 ATT Write，也可能把多个包连续送到串口；STM32 解析器不依赖 BLE 分包边界。安卓应按 `MTU - 3` 拆分写入，且每个图片块等待 ACK 后再发下一块。

## 4. 认证

### 4.1 HELLO

安卓发送 `HELLO_REQ (0x01)`，payload 是 NFC 取得的 12-byte board ID。

STM32 返回 `HELLO_RSP (0x81)`：

| 偏移 | 长度 | 内容 |
|---:|---:|---|
| 0 | 1 | result |
| 1 | 12 | board ID |
| 13 | 16 | 本次随机 challenge |
| 29 | 2 | width = 400 |
| 31 | 2 | height = 300 |
| 33 | 4 | frame bytes = 30000 |
| 37 | 1 | format = 1（native 2bpp） |
| 38 | 2 | max image data = 128 |
| 40 | 1 | 当前状态 |
| 41 | 2 | capabilities：bit0=日历模板、bit1=TIME_SYNC、bit2=本地RTC日历、bit3=持久模板、bit4=BLE OTA、bit5=三模式灯效控制 |

### 4.2 AUTH_PROVE

安卓计算：

```text
authProof = first16(HMAC-SHA256(
  pairingKey,
  ASCII("EPD-AUTH-V1") || boardId || challenge
))
```

然后发送 `AUTH_PROVE (0x02)`，payload 为 16-byte `authProof`。STM32 常量时间校验成功后，只授权一张图片；完成、取消、错误或超时都会清除授权。

双方同时计算本次会话密钥：

```text
sessionKey = HMAC-SHA256(
  pairingKey,
  ASCII("EPD-SESSION-V1") || boardId || challenge
)
```

### 4.3 TIME_SYNC (0x04)

仅允许在认证成功后发送。payload 固定 26 字节：

```text
epochSeconds(u64 LE) | utcOffsetMinutes(i16 LE) | timeTag(16)
```

```text
timeTag = first16(HMAC-SHA256(
  sessionKey,
  ASCII("EPD-TIME-V1") || sequenceLE16 || epochSecondsLE64 ||
  utcOffsetMinutesLE16
))
```

固件接受的时间范围为 2000-01-01 至 2099-12-31，时区偏移范围为 -840 至 +840 分钟。验证成功后 RTC 保存本地时间。

## 5. 图片传输

### 5.1 IMAGE_BEGIN (0x10)

payload 固定 18 字节：

| 偏移 | 长度 | 内容 |
|---:|---:|---|
| 0 | 4 | image ID，安卓生成 |
| 4 | 2 | width = 400 |
| 6 | 2 | height = 300 |
| 8 | 1 | format = 1 |
| 9 | 1 | renderProfile：`0x00`=普通照片，`0x11`=日历布局 V1 |
| 10 | 4 | size = 30000 |
| 14 | 4 | 整帧 IEEE CRC32 |

STM32 先返回 `PREPARING` 状态，随后才给墨水屏上电、复位并初始化。安卓必须等收到成功 ACK 后再发图片块。

日历模式必须先完成 `TIME_SYNC`。该模式在 PREPARING 阶段擦除保留模板区，在所有数据、CRC 与 HMAC 校验成功后才标记模板有效，然后逐行叠加日期、AHT20 室内温度及今日红框并刷新屏幕。

### 5.2 IMAGE_DATA (0x11)

payload 为 `offset(u32 LE) + data(1..128 bytes)`。数据必须从 offset 0 严格连续发送。STM32 每块写入屏控制器后返回 ACK，其中包含下一期待 offset。重复发送一个已经完整接收的旧块只会重发 ACK，不会重复写屏。

### 5.3 IMAGE_END (0x12)

为图片内容生成认证标签：

```text
imageTag = first16(HMAC-SHA256(
  sessionKey,
  ASCII("EPD-IMAGE-V1") ||
  imageIdLE32 || sizeLE32 || imageCrcLE32 || frameBytes
))
```

payload 固定 24 字节：`imageId(u32) + imageCrc32(u32) + imageTag(16)`。

日历模式使用独立标签域，且把渲染配置纳入认证：

```text
calendarTag = first16(HMAC-SHA256(
  sessionKey,
  ASCII("EPD-CALENDAR-V1") || imageIdLE32 || sizeLE32 ||
  imageCrcLE32 || renderProfile || frameBytes
))
```

STM32 只有在字节数、CRC32 和 HMAC 全部正确时才发送刷新命令。刷新期间返回 `REFRESHING`；完成后关屏电源、清除会话并返回 `COMPLETE`。安卓端刷新等待超时建议至少 70 秒。

### 5.4 CANCEL / PING

- `CANCEL (0x13)`：中止传输、丢弃会话、拉低屏幕复位和电源，不刷新不完整图片。
- `PING (0x14)`：返回 ACK，用于检查透明串口链路。

### 5.5 OTA_QUERY / OTA_ENTER

- `OTA_QUERY (0x20)`：认证后发送空 payload，固件返回23字节的 `OTA_INFO (0x85)`，包含当前应用版本、Bootloader协议版本、最大应用长度、应用基地址、STM32设备ID、硬件版本和产品型号。
- `OTA_ENTER (0x21)`：认证后请求进入 Bootloader。payload 和 HMAC 规则见 [BLE_OTA_DESIGN.md](BLE_OTA_DESIGN.md)。成功 ACK 后 STM32 复位，CH9140 会短暂断电，安卓必须重新扫描和连接。

OTA固件块、EPO2通用升级清单和Bootloader响应不使用本节的图片状态机。升级包不绑定唯一board ID，同型号设备共用一个文件；完整定义以 [BLE_OTA_DESIGN.md](BLE_OTA_DESIGN.md) 为准。

## 6. 响应

`ACK (0x82)` payload：

```text
ackedType(u8) | result(u8) | nextOffset(u32 LE) | state(u8)
```

`STATUS (0x83)` payload：

```text
state(u8) | result(u8) | progressPermille(u16 LE) |
received(u32 LE) | expected(u32 LE)
```

`state` 数值：0=IDLE，1=AUTHENTICATED，2=PREPARING，3=RECEIVING，4=VERIFYING，5=REFRESHING，6=COMPLETE，7=ERROR。

主要 result：0=OK，3=设备不匹配，4=未授权，5=忙，6=尺寸错误，7=偏移错误，8=CRC错误，9=墨水屏错误，10=超时，11=串口溢出，12=HMAC验证失败，13=传感器错误，14=时间错误，15=Flash错误，16=OTA请求被拒绝。

## 7. 安卓图片处理要求

1. 使用系统 Photo Picker 选择图片。
2. 按 4:3 比例 center-crop，使图片铺满，不留白边；缩放到 400×300。
3. 将每个像素量化成四种颜色：黑=0、白=1、黄=2、红=3。可选误差扩散抖动以改善照片效果。
4. 行优先、从左上角开始打包；每字节 4 像素，第一个像素放 bits 7..6，随后为 bits 5..4、3..2、1..0。
5. 得到恰好 30,000 字节后计算 CRC32、会话 HMAC，再按上述协议发送。

墨水屏本身断电后可能继续保持最后画面，这是其物理特性；但 STM32 不保存原始图片，复位后无法重新发送上一张图。

## 2026-09-14 灯效扩展（v1 兼容）

新增 `LED_SET=0x05`、`LED_GET=0x06`、`LED_STATE=0x86`，能力位 `0x0020`。
认证后可选择 0=关闭、1=湿度呼吸、2=中心展开、全亮保持 1 秒后渐暗的循环扩散呼吸。NFC 临时覆盖不属于可设置模式。
SET payload 为 mode+16 字节 HMAC，GET 为空；成功回复 35 字节 LED_STATE，错误走既有 ACK。
完整偏移表、HMAC 域、状态同步和示例动画公式见 [ANDROID_LED_CONTROL.md](ANDROID_LED_CONTROL.md)。

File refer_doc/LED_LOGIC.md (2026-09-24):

# 呼吸灯逻辑与验证

- 上电默认全关。PB12 / MODE_SWICH 低电平按下，30 ms 消抖，每次按下只切换一次；长按不重复切换。三模式循环：全关 → 湿度流水呼吸 → 扩散呼吸 → 全关。
- 非 NFC 状态下，按键切换“全关 / 湿度流水呼吸 / 扩散呼吸”。NFC 期间忽略按键，结束后恢复此前模式。
- NFC 检测到射频场时，Q1～Q7 同步呼吸，周期 3 秒。每 40 ms 查询一次；允许 300 ms 短暂射频间歇或读失败，超时恢复背景模式。
- 湿度模式仅用 Q2～Q6，按顺序对应 0～16、16～32、32～48、48～64、64～80 %RH。已覆盖的段依次呼吸，末段按覆盖比例缩放亮度；单灯呼吸持续 1.2 秒，相邻灯延后 300 ms，整体每 3 秒重复。
- 湿度达到或超过 80 %RH 时，Q2～Q6 保持最高亮度。湿度为零或采样无效时不显示进度。Q1、Q7 在湿度模式始终关闭。
- Q1、Q2、Q7 的最大占空比是 80%，Q3～Q6 是 100%。Q0 始终关闭。
- 湿度模式每 2 秒启动一次 AHT20 采样，转换等待分散在主循环中；转换完成后检查忙状态和 CRC。

## 硬件对应

原理图：`SCH_Schematic3_2026-09-11.pdf`。Q1～Q7 指 74HC595 输出编号，不是原理图中同名 MOS 管编号。

SPI2：PA0 为时钟，PA4 为数据；PB14 为锁存；PA8 为低有效 OE。
74HC595 只有一个公共 OE，因此改由 TIM1 定时切换输出掩码，对每路单独调光。
每帧名义时长 4 ms，按亮度变化的时刻产生中断，每帧最多 8 次；实际波形包含短暂锁存消隐和中断延迟。

按键有外部上拉，PB12 配为输入。GPO 未接入 MCU，通过 ST25DV04K 用户 I2C 地址 0x53、EH_CTRL_Dyn（0x2002）bit 2 查询射频场，不改写 NDEF 或 NFC 配置。
寄存器依据：[ST25DV04K/16K/64K 官方数据手册](https://www.st.com/resource/en/datasheet/st25dv16k.pdf)。

HAL_Delay 在主线程等待期间继续查询 NFC，以覆盖墨水屏长时间刷新；中断上下文、I2C 忙或查询重入时跳过。
定时器负责输出，SysTick 负责动画和按键，均不调用阻塞式 HAL 通信函数。
`墨水屏项目.ioc` 已同步按键输入、PA8 输出、SPI2 速率和 TIM1 基础定时配置。外设运行逻辑由 `led_595.c` 管理。

## 已执行验证

`make -j4` 编译、链接成功，输出 `build/epaper_project.elf/.hex/.bin`。
链接器仍报告 newlib 系统调用桩和 RWX LOAD 段警告；此次未更改链接脚本或系统调用实现。

主机回归测试（在项目根目录，需本机 GCC）：

```powershell
gcc -std=c11 -Wall -Wextra -Werror -Itests/led_stubs -ICore/Inc tests/test_led_595.c -o tmp/test_led_595.exe
./tmp/test_led_595.exe
gcc -std=c11 -Wall -Wextra -Werror -Itests/led_stubs -ICore/Inc tests/test_aht20.c -o tmp/test_aht20.exe
./tmp/test_aht20.exe
```

两组均通过。覆盖湿度边界、流水方向、NFC 覆盖、亮度积分、按键消抖及长按、NFC 短暂掉场及通信错误、计时回绕、定时中断掩码、AHT20 转换与 CRC/忙/错误处理。

尚未连接硬件烧录或用示波器验证。上板需确认手机驻留时的射频间歇适配、流水视觉效果，以及蓝牙传输/墨水屏刷新同时工作的表现。
当前固件为带引导程序布局的应用，BIN 起始地址为 `0x08006000`；HEX 自带地址。

## 2026-09-14 三模式扩展

扩散呼吸模式从 Q4 向两侧展开：Q4 → Q3/Q5 → Q2/Q6 → Q1/Q7，每组间隔 300 ms、每灯渐亮 600 ms；1500 ms 时全部亮起，保持 1 秒，再用 600 ms 同步渐暗熄灭，按 3100 ms 周期循环。绿色最高 80%，其他最高 100%。
安卓可通过经过认证的 BLE 接口直接选择三种模式、查询实际效果、时间进度和七路 duty。NFC 期间安卓选择的是背景模式，覆盖效果不中断。
安卓实现与七灯配色见 [ANDROID_LED_CONTROL.md](ANDROID_LED_CONTROL.md)。

新增验证：`test_led_595.c` 已覆盖三模式按键循环、中心展开各组的起止时刻、全亮保持 1 秒、同步渐暗和多周期一致性、重复选择同一模式不重启、非法模式拒绝，以及 NFC 中选择背景模式。
`python tests/test_led_protocol.py` 编译实际报文处理函数，验证未认证/传输忙/错误长度/非法模式/HMAC 篡改拒绝、SET/GET 回包，并用 Python 标准库独立核对 HMAC；已通过。
`make -j4` 已重新生成三模式版本应用固件；仍需安卓接入及实物联调。

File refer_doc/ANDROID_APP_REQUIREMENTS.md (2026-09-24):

# 安卓端应用需求说明

版本：1.3

对应嵌入式协议：`IMAGE_TRANSFER_PROTOCOL.md` v1，BLE OTA v2
目标设备：STM32G070CBT6 + CH9140 + ST25DV04K + 400×300 四色墨水屏

## 2026-09-14 灯光功能增补

设备页增加“关闭 / 湿度呼吸 / 扩散呼吸”三种模式控制，以及完整七灯彩色动画预览。
控制协议、NFC 优先级、中心展开时序、颜色、动画公式和验收要求统一见 [安卓三模式灯效控制与动画规范](ANDROID_LED_CONTROL.md)。
扩散呼吸是 Q4 → Q3/Q5 → Q2/Q6 → Q1/Q7 渐亮展开，全亮保持 1 秒后同步渐暗熄灭并循环；NFC 临时效果仍为全部七灯同步呼吸。
现有“视频、动画不在范围”仅指墨水屏内容，不排除本次新增的 App 灯效预览。

## 1. 目标与范围

安卓应用完成以下闭环：

1. 用户用手机触碰设备 NFC 天线。
2. 系统通过 MIME NDEF 唤起已预装的应用。
3. 应用读取并校验设备 ID 与临时使用的配对密钥。
4. 应用扫描并连接附近唯一的 CH9140 BLE 设备。
5. 应用与 STM32 完成 challenge-response 安全验证。
6. 用户选择一张照片，应用将其裁剪成铺满屏幕的 400×300 图像。
7. 应用把图像量化为黑、白、黄、红四色并编码成 30,000 字节。
8. 应用分包传输图片，显示准备、发送、刷新和完成状态。

NFC 只负责识别目标设备并取得首次配对凭据，不通过 NFC 传输照片。照片只通过 BLE 发送。安卓端不要求支持多设备列表、设备分组或后台自动连接。

## 2. 建议技术基线

- Kotlin。
- 单 Activity，可使用 Jetpack Compose；传统 View 也可以。
- 建议 `minSdk 26`，构建时使用当前稳定的 `compileSdk/targetSdk`。
- 使用 `ActivityResultContracts.PickVisualMedia` 选择单张图片；该接口在可用时使用系统 Photo Picker，并能在旧系统回退到兼容选择器。
- BLE 使用 Android 原生 `BluetoothGatt`。
- 异步代码使用 Kotlin Coroutines、`StateFlow` 和单写入队列。
- 图片转换、CRC 和 HMAC 放在 `Dispatchers.Default`，不要阻塞主线程。

Android 官方参考：

- [NFC 与 NDEF](https://developer.android.com/develop/connectivity/nfc/nfc)
- [蓝牙权限](https://developer.android.com/develop/connectivity/bluetooth/bt-permissions)
- [BLE 数据传输](https://developer.android.com/develop/connectivity/bluetooth/ble/transfer-ble-data)
- [Photo Picker](https://developer.android.com/reference/androidx/activity/result/contract/ActivityResultContracts.PickVisualMedia)

## 3. 用户界面

### 3.1 首页/等待碰一碰

显示：

- “请用手机触碰设备 NFC 区域”。
- NFC、蓝牙及“附近设备”权限状态。
- 最近一次错误及“重新尝试”按钮。

未从有效 NFC 数据进入时，不允许直接选择和发送图片。

### 3.2 已识别设备页

显示：

- 设备短 ID：建议显示 board ID 最后 4 字节的十六进制。
- BLE 状态：扫描中、连接中、验证中、已就绪。
- “选择照片”按钮，仅在认证成功后启用。

附近只有一个目标设备，因此不提供设备列表；但是连接完成后仍必须通过 `HELLO_RSP` 返回的 board ID 做最终匹配，不能只相信蓝牙名称。

### 3.3 图片预览页

同时显示：

- 原图裁剪预览。
- 最终 400×300 四色效果预览。
- “重新选择”和“发送到墨水屏”按钮。

预览必须与实际发送的 30,000 字节来自同一份转换结果，防止预览和屏幕结果不一致。

### 3.4 传输页

显示以下阶段：

- 墨水屏准备中。
- 数据发送中：百分比、已发送字节数。
- 图片验证中。
- 墨水屏刷新中。
- 完成或失败。

刷新阶段可能明显长于数据传输阶段。收到 STM32 的 `COMPLETE` 状态前，不能提示“显示完成”。

## 4. NFC 接口

### 4.1 Manifest

应用需要声明 NFC 和 BLE 功能：

```xml
<uses-permission android:name="android.permission.NFC" />

<uses-feature
    android:name="android.hardware.nfc"
    android:required="true" />
<uses-feature
    android:name="android.hardware.bluetooth_le"
    android:required="true" />
```

负责接收 NFC 的 Activity 注册精确 MIME，不使用通配符：

```xml
<activity
    android:name=".MainActivity"
    android:exported="true">

    <intent-filter>
        <action android:name="android.intent.action.MAIN" />
        <category android:name="android.intent.category.LAUNCHER" />
    </intent-filter>

    <intent-filter>
        <action android:name="android.nfc.action.NDEF_DISCOVERED" />
        <category android:name="android.intent.category.DEFAULT" />
        <data android:mimeType="application/vnd.epaper.pair" />
    </intent-filter>
</activity>
```

需要同时处理应用冷启动时的 `intent` 和应用已打开时的 `onNewIntent()`。

### 4.2 NDEF payload 校验

从第一个 MIME NDEF Record 中读取 payload，必须逐项校验：

| 偏移 | 长度 | 要求 |
|---:|---:|---|
| 0 | 4 | 必须为 ASCII `EPD1` |
| 4 | 1 | 必须为协议版本 `1` |
| 5 | 12 | board ID |
| 17 | 16 | pairing key |
| 33 | 1 | bit0 必须为 1，表示要求 HMAC |

payload 长度必须恰好为 34 字节。任何长度、Magic、版本或 flags 错误都应拒绝，并显示“不是受支持的设备”。

### 4.3 凭据生命周期

- pairing key 默认只保存在当前进程内存中，不写日志、不上传、不截图显示。
- 用户退出传输流程、认证失败或应用进程终止时清除内存中的 key、challenge 和 session key。
- MVP 每次重新进入完整传图流程都要求重新碰 NFC。
- 如果以后需要记住设备，必须使用 Android Keystore 保护密钥，不能明文写入 SharedPreferences 或数据库。

## 5. 蓝牙权限

Android 12/API 31 及以上声明并动态申请：

```xml
<uses-permission android:name="android.permission.BLUETOOTH_SCAN"
    android:usesPermissionFlags="neverForLocation" />
<uses-permission android:name="android.permission.BLUETOOTH_CONNECT" />
```

应用不进行 BLE 广播，因此不需要 `BLUETOOTH_ADVERTISE`。

兼容 Android 11 及以下时声明：

```xml
<uses-permission android:name="android.permission.BLUETOOTH"
    android:maxSdkVersion="30" />
<uses-permission android:name="android.permission.BLUETOOTH_ADMIN"
    android:maxSdkVersion="30" />
<uses-permission android:name="android.permission.ACCESS_FINE_LOCATION"
    android:maxSdkVersion="30" />
```

权限被拒绝时给出明确说明和“打开系统设置”入口，不应无限重复弹窗。

## 6. CH9140 BLE/GATT 接口

### 6.1 UUID

使用标准 Bluetooth Base UUID 展开 16-bit UUID：

- Service：`0000fff0-0000-1000-8000-00805f9b34fb`
- STM32 → 手机 Notify：`0000fff1-0000-1000-8000-00805f9b34fb`
- 手机 → STM32 Write：`0000fff2-0000-1000-8000-00805f9b34fb`
- CCCD：`00002902-0000-1000-8000-00805f9b34fb`

### 6.2 扫描和连接

1. NFC payload 校验成功后才开始 BLE 扫描。
2. 优先使用 FFF0 Service UUID 过滤；如果 CH9140 广播包未携带 Service UUID，可退回设备名称前缀过滤。
3. 扫描超时建议 10 秒。
4. 因附近只有一个设备，找到首个候选后即可停止扫描并连接。
5. 连接后执行 service discovery，确认 FFF0、FFF1、FFF2 全部存在。
6. 为 FFF1 调用 `setCharacteristicNotification(true)` 并写入 CCCD `ENABLE_NOTIFICATION_VALUE`。
7. 必须等待 CCCD 写成功，再发送第一个 `HELLO_REQ`。
8. 可请求较大 MTU，例如 247；但业务层不能依赖请求一定成功。

连接到错误设备不会通过 board ID 和 HMAC 校验。

### 6.3 写入策略

- 优先使用 FFF2 的 Write With Response。
- 如果模块只提供 Write Without Response，应用必须维持单写入队列，等待 Android 写回调/本地节流后才能继续。
- 一个应用层包可按 `当前 MTU - 3` 拆成多个 BLE 写操作。
- 不允许多个协程同时调用 GATT 写入。
- STM32 的解析器不依赖 BLE 通知或写入边界，因此 FFF1 收到的数据统一追加到字节流解析缓冲区。

## 7. 安全验证

### 7.1 认证流程

完整时序如下：

```mermaid
sequenceDiagram
    participant U as 用户
    participant A as 安卓应用
    participant N as NFC/ST25DV04K
    participant B as CH9140/STM32
    participant E as 墨水屏

    U->>N: 手机碰一碰
    N->>A: boardId + pairingKey
    A->>B: BLE连接并订阅FFF1
    A->>B: HELLO_REQ(boardId)
    B->>A: HELLO_RSP(challenge, capabilities)
    A->>B: AUTH_PROVE(HMAC)
    B->>A: ACK(认证成功)
    U->>A: 选择照片并确认发送
    A->>B: IMAGE_BEGIN
    B->>E: 上电、复位、初始化
    B->>A: ACK(可以发送)
    loop 每块最多128字节
        A->>B: IMAGE_DATA(offset, data)
        B->>E: 写入屏控制器RAM
        B->>A: ACK(nextOffset)
    end
    A->>B: IMAGE_END(CRC32, imageHMAC)
    B->>B: 校验长度、CRC32和HMAC
    B->>E: 刷新并休眠
    B->>A: STATUS(COMPLETE)
```

HMAC、session key 和 image tag 的确切拼接规则见 [IMAGE_TRANSFER_PROTOCOL.md](IMAGE_TRANSFER_PROTOCOL.md)。所有拼接必须按原始字节执行，不能把 board ID、challenge 或 CRC 转成十六进制字符串后再计算。

### 7.2 安全要求

- HMAC 使用 `HmacSHA256`。
- 使用 `MessageDigest.isEqual()` 或等价常量时间方式比较本地敏感值。
- 不接受 board ID 不匹配的 `HELLO_RSP`。
- challenge 每次连接重新获取，不能复用上一次认证结果。
- 一次认证只允许传一张图片。
- 图片 HMAC 验证覆盖完整 30,000 字节，不能只依赖 CRC32。
- CRC32 用于发现传输错误；HMAC 用于证明图片来自持有 NFC 配对密钥的应用。
- 当前协议提供身份认证和完整性，不提供图片内容加密。日志中禁止输出 pairing key、session key、auth proof 和 image tag。

## 8. 图片选择和转换

### 8.1 选择图片

使用单图片 Photo Picker：

```kotlin
val picker = registerForActivityResult(
    ActivityResultContracts.PickVisualMedia()
) { uri ->
    // uri == null 表示用户取消
}

picker.launch(
    PickVisualMediaRequest(ActivityResultContracts.PickVisualMedia.ImageOnly)
)
```

应用只需要当前读取权限，不需要申请整个相册的存储权限。处理完成后不保存原始照片副本。

### 8.2 解码与铺满

1. 读取图片方向信息并纠正旋转。
2. 将透明像素先合成到白色背景。
3. 按 4:3 比例进行 center-crop：
   - 原图过宽：裁掉左右部分。
   - 原图过高：裁掉上下部分。
4. 缩放到严格的 400×300。
5. 禁止拉伸变形和添加留白边。
6. 大图片先按目标尺寸进行采样解码，避免 OOM。

### 8.3 四色量化

目标色码固定为：

| 色码 | 颜色 | 建议预览 RGB 初值 |
|---:|---|---|
| 0 | 黑 | `#000000` |
| 1 | 白 | `#FFFFFF` |
| 2 | 黄 | `#FFD700` |
| 3 | 红 | `#DC0000` |

建议使用带权颜色距离或 CIELAB 选择最近颜色。照片模式可增加 Floyd–Steinberg 误差扩散；同时提供“关闭抖动”选项，便于文字、二维码或纯色图使用。实际 RGB 可根据屏幕样品后续标定，但 2-bit 色码不能更改。

### 8.4 2bpp 打包

- 行优先，从左上角开始。
- 每行 400 像素，即 100 字节。
- 共 300 行，即 30,000 字节。
- 每字节打包 4 个像素：

```text
byte = p0 << 6 | p1 << 4 | p2 << 2 | p3
```

其中 `p0` 是最左侧像素。输出长度不是 30,000 字节时必须在安卓端报错，不能开始传输。

## 9. 应用层协议状态机

底层数据包字段和消息 payload 以 [IMAGE_TRANSFER_PROTOCOL.md](IMAGE_TRANSFER_PROTOCOL.md) 为唯一准则。

建议安卓状态：

```text
WaitingForNfc
  -> Scanning
  -> Connecting
  -> DiscoveringServices
  -> EnablingNotifications
  -> Authenticating
  -> Ready
  -> PreparingImage
  -> PreparingPanel
  -> Sending(progress)
  -> Verifying
  -> Refreshing
  -> Complete
  -> Error(recoverable, message)
```

状态转换必须由真实 GATT 回调和 STM32 ACK/STATUS 驱动，不能仅靠固定延时。

### 9.1 发送算法

1. 生成随机 `imageId`。
2. 对 30,000 字节计算 IEEE CRC32。
3. 发送 `IMAGE_BEGIN`，等待同 sequence 的成功 ACK。
4. 从 offset 0 开始，每块最多 128 字节发送 `IMAGE_DATA`。
5. 每块等待 ACK；以 ACK 中的 `nextOffset` 为准推进。
6. ACK 丢失时可用同 offset 重发同一块；STM32 会识别完整重复块且不会重复写屏。
7. 全部数据发送后计算 image HMAC，发送 `IMAGE_END`。
8. 等待 `COMPLETE` STATUS；刷新阶段超时建议至少 70 秒。

每个普通命令 ACK 超时建议 2 秒，最多重试 3 次。`IMAGE_BEGIN` 因包含屏幕上电初始化，超时应放宽到 65 秒。

### 9.2 字节流解析器

- 搜索 Magic `45 50` 进行同步。
- 收齐固定 8-byte header 后读取 payload length。
- payload length 大于 132 立即丢弃并重新同步。
- 收齐 payload 和末尾 CRC32 后才分发消息。
- CRC 错误的响应包不能驱动状态机。
- 同时校验响应 sequence；异步 STATUS 可以使用请求 sequence 或 0。

## 10. 断开、取消与恢复

- 用户主动取消：发送 `CANCEL`，等待 ACK，然后断开 GATT。
- 发送中断开：STM32 在约 10 秒无有效数据后断电并丢弃未完成帧。
- 重连后不支持从断电的屏幕会话继续；重新执行 HELLO、AUTH 和整帧发送。
- 如果应用进程仍保存 NFC key，可以在同一次前台操作内重新认证；进程已丢失凭据则要求重新碰 NFC。
- CRC 或 HMAC 失败必须整帧重传。
- `EPD_ERROR` 提示用户检查设备电源或重新启动设备，不自动无限重试高压刷新。
- 应用进入后台时 MVP 应暂停新传输；发送已经开始时保持页面前台并使用 `FLAG_KEEP_SCREEN_ON`。若产品要求后台继续，再增加合规的 foreground service。

## 11. 错误提示映射

| result | 安卓提示 | 建议动作 |
|---:|---|---|
| 1 | 数据包损坏 | 重发当前命令 |
| 2 | 应用与固件协议版本不一致 | 停止并提示升级 |
| 3 | 连接的不是刚才碰触的设备 | 断开并重新扫描 |
| 4 | 会话未认证或已过期 | 重新执行 HELLO/AUTH |
| 5 | 设备忙 | 等待或稍后重试 |
| 6 | 图片尺寸/格式错误 | 重新转换图片 |
| 7 | 数据偏移不一致 | 按 ACK 的 nextOffset 重发 |
| 8 | 整帧 CRC 错误 | 重新开始整帧传输 |
| 9 | 墨水屏初始化或刷新失败 | 停止，提示检查设备 |
| 10 | 设备接收超时 | 重新认证并重传 |
| 11 | STM32 串口缓冲溢出 | 降低发送并发，严格等待 ACK |
| 12 | HMAC 验证失败 | 清除会话，要求重新碰 NFC |

## 12. 建议代码模块

```text
nfc/
  NfcIntentHandler       解析NDEF和校验pairing payload
ble/
  BleScanner             扫描唯一CH9140
  BleGattClient          连接、发现服务、订阅、串行写入
protocol/
  PacketCodec            数据包编码、流式解码、packet CRC32
  SecuritySession        AUTH、session key、image HMAC
image/
  ImageDecoder           方向纠正、采样解码、center-crop
  FourColorQuantizer     四色量化和可选抖动
  FramePacker            2bpp/30000字节打包
transfer/
  TransferCoordinator    ACK、超时、重试、进度、取消
ui/
  MainViewModel          StateFlow统一UI状态
```

建议核心接口：

```kotlin
data class PairingInfo(
    val protocolVersion: Int,
    val boardId: ByteArray,
    val pairingKey: ByteArray,
)

interface ImageEncoder {
    suspend fun encode(uri: Uri): EncodedFrame
}

data class EncodedFrame(
    val bytes: ByteArray,       // 必须为30000
    val crc32: UInt,
    val preview: Bitmap,
)

interface DeviceSession {
    suspend fun connectAndAuthenticate(pairing: PairingInfo)
    suspend fun send(frame: EncodedFrame): Flow<TransferProgress>
    suspend fun cancel()
    suspend fun disconnect()
}
```

对包含密钥的 `ByteArray`，使用完后调用 `fill(0)`；不要把它放入可序列化的 UI state、savedInstanceState 或崩溃上报附件。

## 13. 验收测试

### 13.1 单元测试

- NFC payload：正常、错误 Magic、错误版本、错误长度、flags 缺失。
- CRC32 标准向量：ASCII `123456789` 应得到 `0xCBF43926`。
- HMAC-SHA256 标准向量与固件域字符串拼接测试。
- packet codec：随机拆包、粘包、Magic 前噪声、CRC 错误、超长 payload。
- 图片打包：400×300 单色图分别得到 `00`、`55`、`AA`、`FF` 填充帧。
- center-crop：横图、竖图、透明 PNG、带 EXIF 旋转 JPEG。

### 13.2 BLE 集成测试

- MTU 23 和较大 MTU 下都能完成传输。
- 每个应用层包被拆成多个 BLE write 时仍能解析。
- 故意丢弃 ACK 后重发同 offset，不应造成屏幕数据错位。
- 发送错误 offset 时，应用按 `nextOffset` 恢复。
- 传输中断开后，设备超时断屏电源，重新连接能重新传图。
- 连接另一台 CH9140 时 board ID 校验必须失败。

### 13.3 安全测试

- 未碰 NFC 直接连接 BLE，不能执行 `IMAGE_BEGIN`。
- 使用错误 key、旧 challenge 或修改后的 auth proof，认证必须失败。
- 传输中修改任一图片字节但不改 tag，必须 HMAC 失败且不刷新。
- 修改 CRC 后重新计算 packet CRC，但没有正确 image HMAC，仍必须失败。
- 认证成功后只允许完成一张图；第二张必须重新认证。
- 日志、崩溃报告和界面不得出现任何密钥。

### 13.4 最终硬件验收

1. 全新启动设备，手机碰 NFC 后应用自动打开。
2. 10 秒内连接并通过认证。
3. 选择横图和竖图，预览均铺满且无变形。
4. 完成 30,000 字节传输，进度达到 100%。
5. 墨水屏仅在整帧校验完成后刷新，显示内容与四色预览一致。
6. 刷新后设备关闭墨水屏高压，BLE 保持可供下一次连接。
7. 设备断电后 MCU 不保存原图；墨水屏可能因物理特性继续保持最后画面，这是正常现象。

## 14. BLE OTA升级

### 14.1 客户端职责

安卓应用只负责选择并传输由发布工具生成的 `.epota` 文件，不能持有发布密钥，也不能在手机端为任意 `.bin` 生成发布标签。升级包、Bootloader消息和Flash布局的唯一规范为 [BLE_OTA_DESIGN.md](BLE_OTA_DESIGN.md)。

升级入口仅在以下条件全部满足时启用：

- 已通过NFC取得本机board ID；
- 已完成`HELLO/AUTH_PROVE`；
- `HELLO_RSP.capabilities` bit4为1；
- `OTA_QUERY`返回的最大应用长度能够容纳升级包；
- `.epota`为EPO2格式，且STM32设备ID、产品型号、硬件版本与`OTA_INFO`完全相同；
- 新版本严格大于当前版本。

### 14.2 正常应用阶段

1. 发送空payload的`OTA_QUERY (0x20)`。
2. 解析23字节的`OTA_INFO (0x85)`，取得当前版本、Bootloader协议版本、最大应用长度、应用地址、STM32设备ID、硬件版本和产品型号。
3. 生成32-bit随机nonce。
4. 计算：

```text
otaEnterTag = first16(HMAC-SHA256(
  sessionKey,
  ASCII("EPD-OTA-ENTER-V1") || sequenceLE16 ||
  firmwareVersionLE32 || nonceLE32
))
```

5. 发送`OTA_ENTER (0x21)`：

```text
firmwareVersionLE32 | nonceLE32 | otaEnterTag(16)
```

6. 收到成功ACK后进入`WaitingForBootloader`，预期BLE断开，不能把该断开显示为升级失败。

### 14.3 Bootloader重连阶段

STM32复位期间PB10恢复默认状态，CH9140会短暂掉电。安卓应在成功ACK后：

1. 主动关闭旧`BluetoothGatt`；
2. 等待约500 ms后重新扫描，整体重连超时建议20秒；
3. 重新连接FFF0/FFF1/FFF2并订阅通知；
4. 发送`BOOT_HELLO (0x30)`；
5. 校验37字节响应中的模式为Bootloader、board ID一致，并再次核对STM32设备ID、硬件版本和产品型号；
6. 发送`.epota`文件偏移8..87的80-byte通用清单作为`OTA_BEGIN (0x31)`；
7. 等待擦除完成ACK，超时建议10秒；
8. 按offset发送`OTA_DATA (0x32)`，每块最多128字节且严格等待ACK；
9. 发送空payload的`OTA_END (0x33)`；
10. 等待COMPLETE状态和设备再次复位；
11. 重连正常应用，执行`OTA_QUERY`确认版本。

客户端以Bootloader ACK中的`nextOffset`为准。ACK丢失时允许重发完全相同的旧块；收到`BAD_OFFSET`时从设备返回的offset继续。升级包数据不得进行解压、重编码或修改。

### 14.4 建议安卓状态

```text
OtaChecking
  -> OtaAuthorizing
  -> WaitingForBootloader
  -> ReconnectingBootloader
  -> Erasing
  -> Uploading(progress)
  -> OtaVerifying
  -> WaitingForApplication
  -> OtaComplete
  -> OtaRecoveryRequired
```

从`OTA_BEGIN`成功以后，即使应用退出或BLE中断，旧应用也可能已经被擦除。界面必须提示用户保持设备供电，并提供“重新连接并重新上传完整固件”，不能只提供返回首页。

### 14.5 OTA测试

- 修改`.epota`中任意固件字节，最终必须返回HASH错误且不启动。
- 修改版本、长度、目标硬件字段或release tag，必须在擦除应用前拒绝。
- 每个数据块在不同ATT边界拆分时仍可解析。
- 在10%、50%、99%处断电，重新上电后Bootloader仍广播且可重新升级。
- 丢弃任意一个ACK后重发同offset，Flash内容不能重复错位。
- 同型号的不同设备必须能够使用同一个EPO2升级包。
- 修改EPO2的产品型号、硬件版本或STM32设备ID后必须返回WRONG_DEVICE。
- OTA成功后版本必须更新，图片、日历、RTC和温湿度功能必须回归通过。

建议增加模块：

```text
ota/
  OtaPackageReader      校验EPO2容器、目标硬件、版本和长度
  OtaCoordinator        两阶段连接、超时、重试和进度
  BootProtocolCodec     Bootloader ACK/STATUS解析
```

## 15. 不在当前版本范围内

- iOS 客户端。
- 多设备列表和批量下发。
- 图片历史、云同步、账号体系。
- BLE 图片内容加密。
- STM32 Flash 图片持久化。
- 视频、动画和局部刷新。

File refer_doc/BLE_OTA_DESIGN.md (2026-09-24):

# STM32G070 + CH9140 BLE OTA原理与接口说明

版本：2.0

适用硬件：STM32G070CBT6、CH9140、ST25DV04K、400×300四色墨水屏

传输链路：Android/Windows BLE GATT → CH9140透明串口 → STM32 USART2 115200 8N1

## 1. 设计目标

OTA只更新业务Application，Bootloader永远保留。升级中途掉电会导致Application无效，但重新上电后Bootloader仍会打开CH9140并允许重新上传，从而避免必须拆机连接ST-Link。

CH9140不负责解析或写入STM32固件，它只转发字节。Flash擦除、写入、哈希校验、发布认证和启动跳转全部由STM32 Bootloader完成。

## 2. Flash布局

STM32G070CBT6有128 KiB单Bank Flash，擦除页为2 KiB：

| 区域 | 起始地址 | 结束地址 | 大小 | 页 |
|---|---:|---:|---:|---:|
| Bootloader | `0x08000000` | `0x08005FFF` | 24 KiB | 0..11 |
| Application | `0x08006000` | `0x08017FFF` | 72 KiB | 12..47 |
| 日历底图 | `0x08018000` | `0x0801F7FF` | 30 KiB | 48..62 |
| OTA Metadata | `0x0801F800` | `0x0801FFFF` | 2 KiB | 63 |

Application链接地址和向量表均为`0x08006000`。当前Application约34 KiB，Bootloader约11 KiB，均低于各自上限。

日历底图本体为30,000字节，头部32字节，合计可放入15页。`CalendarFlash_Begin()`只擦除页48..62，不能擦除OTA元数据页63。

## 3. 上电决策

Bootloader位于硬件启动地址`0x08000000`，每次上电或复位首先运行。RTC备份寄存器DR3用于传递一次性OTA请求：

```text
OTA_BOOT_REQUEST_MAGIC = 0x4F544131  // OTA1
```

Bootloader流程：

```text
读取并清除DR3
  ├─ 没有OTA请求且Application有效：立即跳转0x08006000
  ├─ 有OTA请求：打开CH9140并等待升级，最长120秒
  └─ Application无效/升级中断：永久停留在OTA恢复模式
```

为支持首次工厂迁移，OTA元数据页完全擦除且Application向量合法时允许启动一次由SWD写入的重定位Application。正式OTA在擦除Application前必定先写入`OTAP`事务标志，因此中断升级不会错误走工厂回退路径。

## 4. Application进入OTA

### 4.1 OTA_QUERY

完成`HELLO/AUTH_PROVE`后发送空payload：

```text
type = 0x20
```

返回`OTA_INFO (0x85)`，payload固定23字节：

| 偏移 | 长度 | 内容 |
|---:|---:|---|
| 0 | 1 | result |
| 1 | 4 | Application版本LE32 |
| 5 | 2 | Bootloader协议版本LE16 |
| 7 | 4 | Application最大字节数，当前73728 |
| 11 | 4 | Application基地址，`0x08006000` |
| 15 | 2 | STM32设备ID，当前`0x0460` |
| 17 | 2 | 硬件版本，当前`1` |
| 19 | 4 | 产品型号，当前`0x00000001` |

### 4.2 OTA_ENTER

payload固定24字节：

```text
firmwareVersionLE32 | nonceLE32 | otaEnterTag(16)
```

```text
otaEnterTag = first16(HMAC-SHA256(
  sessionKey,
  ASCII("EPD-OTA-ENTER-V1") || sequenceLE16 ||
  firmwareVersionLE32 || nonceLE32
))
```

验证成功后Application关闭墨水屏电源，在RTC DR3写入OTA请求，发送成功ACK并执行`NVIC_SystemReset()`。

## 5. BLE断开与重连

板上Q8由PB10控制且低电平使能。MCU复位时PB10暂时高阻，由外部电阻把Q8关闭，因此CH9140会短暂掉电，原BLE连接必然可能断开。

Bootloader重新配置：

- PB10=LOW：打开3V3_BT；
- PB15=HIGH：CH9140正常工作；
- PA2=USART2_TX，PA3=USART2_RX；
- USART2=115200、8N1；
- 上电稳定等待约520 ms。

客户端必须把OTA_ENTER后的首次断开视为正常状态，并重新扫描、连接、发现FFF0服务、订阅FFF1、向FFF2写入。

## 6. Bootloader数据包

仍使用普通协议的包封装：

```text
45 50 | version=01 | type | sequenceLE16 | payloadLengthLE16 |
payload | IEEE-CRC32LE
```

CRC32覆盖`version`至payload，不覆盖Magic。payload最大132字节。BLE ATT分包边界不等于应用数据包边界，客户端和Bootloader都按字节流解析。

### 6.1 消息类型

| 类型 | 值 | 方向 | 说明 |
|---|---:|---|---|
| BOOT_HELLO | `0x30` | 客户端→Boot | 空payload |
| OTA_BEGIN | `0x31` | 客户端→Boot | 80字节发布清单 |
| OTA_DATA | `0x32` | 客户端→Boot | offset+最多128字节 |
| OTA_END | `0x33` | 客户端→Boot | 空payload |
| OTA_ABORT | `0x34` | 客户端→Boot | 空payload，保持Application无效 |
| PING | `0x14` | 客户端→Boot | 链路检查 |
| BOOT_HELLO_RSP | `0xB0` | Boot→客户端 | Bootloader身份和能力 |
| OTA_ACK | `0xB1` | Boot→客户端 | 命令结果和下一offset |
| OTA_STATUS | `0xB2` | Boot→客户端 | 阶段与进度 |

### 6.2 BOOT_HELLO_RSP

payload固定37字节：

| 偏移 | 长度 | 内容 |
|---:|---:|---|
| 0 | 1 | result |
| 1 | 1 | mode=`1`，表示Bootloader |
| 2 | 2 | Bootloader协议版本 |
| 4 | 1 | Boot状态 |
| 5 | 12 | board ID |
| 17 | 4 | 当前有效固件版本，无则0 |
| 21 | 4 | 最大Application大小 |
| 25 | 4 | 当前期待offset |
| 29 | 2 | STM32设备ID，当前`0x0460` |
| 31 | 2 | 硬件版本，当前`1` |
| 33 | 4 | 产品型号，当前`0x00000001` |

### 6.3 OTA_BEGIN

payload固定80字节，可直接从`.epota`头部偏移8开始读取：

| 偏移 | 长度 | 内容 |
|---:|---:|---|
| 0 | 2 | STM32设备ID=`0x0460` |
| 2 | 2 | 硬件版本=`1` |
| 4 | 4 | 产品型号=`0x00000001` |
| 8 | 4 | firmwareVersion LE32 |
| 12 | 4 | firmwareSize LE32 |
| 16 | 32 | firmware SHA-256 |
| 48 | 32 | releaseTag HMAC-SHA256 |

Bootloader在擦除旧Application之前完成STM32设备ID、硬件版本、产品型号、固件版本、大小和releaseTag验证。升级包不包含STM32唯一UID，因此同一硬件型号的所有设备共用一个文件。当前版本要求新固件版本严格大于已验证版本。

验证通过后先擦除元数据页并写`OTAP`事务标志，再擦除全部Application页。擦除阶段先发STATUS，擦除结束后才返回OTA_BEGIN成功ACK。

### 6.4 OTA_DATA

```text
offsetLE32 | data(1..128)
```

- offset从0严格连续增长；
- 每块写入Flash并回读成功后才ACK；
- ACK丢失时可重发已经完整提交的旧块；
- 最后一块可以不是8字节倍数，Bootloader用`0xFF`补齐Double Word，但SHA只覆盖真实固件长度；
- OTA_DATA 15秒无活动进入ERROR，重新发送OTA_BEGIN可从头恢复。

### 6.5 OTA_END

payload为空。Bootloader依次执行：

1. 补齐并写入最后一个Double Word；
2. 结束流式SHA-256；
3. 从Flash重新读取Application并再次计算SHA-256；
4. 两个结果都与清单hash比较；
5. 检查初始MSP位于`0x20000000..0x20009000`；
6. 检查Reset Handler为Thumb地址且位于固件长度内；
7. 写入固件版本、长度、hash和releaseTag；
8. 最后一个Flash写操作提交`OTAV`有效标志；
9. 返回完成状态并复位。

### 6.6 ACK与STATUS

Bootloader ACK固定7字节，与普通图片ACK字段顺序不同：

```text
ackedType(u8) | result(u8) | bootState(u8) | nextOffset(u32 LE)
```

STATUS与普通协议结构相同：

```text
bootState(u8) | result(u8) | progressPermille(u16 LE) |
received(u32 LE) | expected(u32 LE)
```

Boot状态：0=IDLE，1=ERASING，2=RECEIVING，3=VERIFYING，4=COMPLETE，5=ERROR。

Boot result：0=OK，1=包损坏，2=协议版本错误，3=设备不匹配，4=状态错误，5=长度错误，6=offset错误，7=hash错误，8=发布认证失败，9=Flash错误，10=超时，11=拒绝降级，12=向量表错误。

## 7. EPO2通用升级包

使用命令生成：

```powershell
python tools/package_ota.py build/epaper_project.bin `
  --version 1.0.2 `
  --development-key
```

输出扩展名为`.epota`。文件头固定88字节：

| 文件偏移 | 长度 | 内容 |
|---:|---:|---|
| 0 | 4 | ASCII `EPO2` |
| 4 | 1 | 容器版本=`2` |
| 5 | 1 | flags，当前=`0` |
| 6 | 2 | 文件头长度=`88` |
| 8 | 2 | STM32设备ID=`0x0460` |
| 10 | 2 | 硬件版本=`1` |
| 12 | 4 | 产品型号=`0x00000001` |
| 16 | 4 | 固件版本 |
| 20 | 4 | 固件长度 |
| 24 | 32 | SHA-256 |
| 56 | 32 | releaseTag |
| 88 | N | Application二进制 |

Android发送OTA_BEGIN时使用文件偏移8..87，发送OTA_DATA时使用偏移88之后的数据。

`releaseTag`计算方式：

```text
HMAC-SHA256(
  releaseKey,
  ASCII("EPD-OTA-RELEASE-V2") || stm32DeviceIdLE16 ||
  hardwareRevisionLE16 || productIdLE32 ||
  firmwareVersionLE32 || firmwareSizeLE32 || firmwareSHA256
)
```

仓库中的key仅用于开发测试。安卓只收到已打包的`.epota`文件，不得获得releaseKey。除非硬件真的发生变化，否则不要通过命令行覆盖`--product-id`或`--hardware-revision`。

## 8. 安全边界

当前V2实现包含两层认证：

1. NFC派生session key保护OTA_ENTER，防止未配对手机让正常设备进入升级模式；
2. Bootloader独立release key验证升级包，持有NFC pairing key的客户端也不能制作任意固件。

board ID仍用于NFC配对、`HELLO`设备匹配以及`OTA_ENTER`会话认证，但不进入EPO2发布签名。这样既保持每台设备的近场授权，又允许同型号设备共用一个正式升级包。

开发版发布认证使用HMAC-SHA256。其局限是Bootloader内部仍保存对称密钥；如果攻击者能读出Flash，就能伪造固件。量产建议替换为ECDSA P-256或Ed25519，Bootloader只保存公钥，私钥留在离线发布系统或HSM中。

在硬件实测稳定以后，应通过STM32CubeProgrammer Option Bytes把Bootloader页0..11设置为WRP写保护。不要在尚未验证恢复路径时直接修改RDP/WRP；错误Option Bytes可能造成调试和返修困难。

OTA不提供固件内容加密，固件二进制可能被观察，但不能在不知道发布密钥的情况下修改并通过认证。

## 9. 断电恢复

本芯片剩余空间不足以保留完整A/B双应用，因此OTA开始后旧Application会被擦除。安全性来自不可擦除的Bootloader和事务标志：

- 擦除Application前写入`OTAP`；
- 任何阶段断电后都不会跳转到部分固件；
- 上电后Bootloader重新打开BLE并永久等待有效OTA_BEGIN；
- 只有完整hash、回读hash、发布认证和向量表全部通过后才写`OTAV`；
- `OTAV`写入成功后复位并启动新Application。

## 10. 首次烧录与构建

构建Application：

```powershell
make
```

构建Bootloader：

```powershell
make -f Bootloader/Makefile
```

首次必须使用ST-Link或串口ROM Bootloader分别烧录：

1. `build_bootloader/epaper_bootloader.hex`，地址由HEX指定为`0x08000000`；
2. `build/epaper_project.hex`，地址由HEX指定为`0x08006000`。

首次安装可全片擦除；以后单独更新Application时不能全片擦除，否则会删除Bootloader。烧录后先确认正常上电能够从Bootloader跳转到Application，再启用页0..11的WRP。

每次发布必须递增`OTA_APPLICATION_VERSION`并用相同版本生成`.epota`。客户端不能只修改容器版本字段，因为releaseTag会失效。

从旧的设备专用EPO1/Bootloader协议V1迁移到EPO2时，必须通过ST-Link更新Bootloader，因为Bootloader本身不能通过本协议自更新。建议全片擦除后依次烧录新版Bootloader和Application；如果必须保留其他Flash数据，至少还要擦除旧OTA元数据页`0x0801F800..0x0801FFFF`。旧Bootloader不能接收EPO2，旧EPO1包也不能用于新版Bootloader。

## 11. 验收清单

- Bootloader HEX最低地址为`0x08000000`且不超过`0x08005FFF`；
- Application HEX最低地址为`0x08006000`且不超过`0x08017FFF`；
- 日历写入不触碰页63；
- 普通启动不会出现明显BLE额外等待；
- OTA_ENTER失败不会复位；
- OTA_ENTER成功后客户端能处理一次预期断连；
- 修改清单或固件任一字节均不能启动；
- 传输任意阶段断电后仍能重新发现CH9140并完整恢复；
- OTA完成后版本查询、图片传输、RTC、日历和5分钟温湿度刷新全部正常。

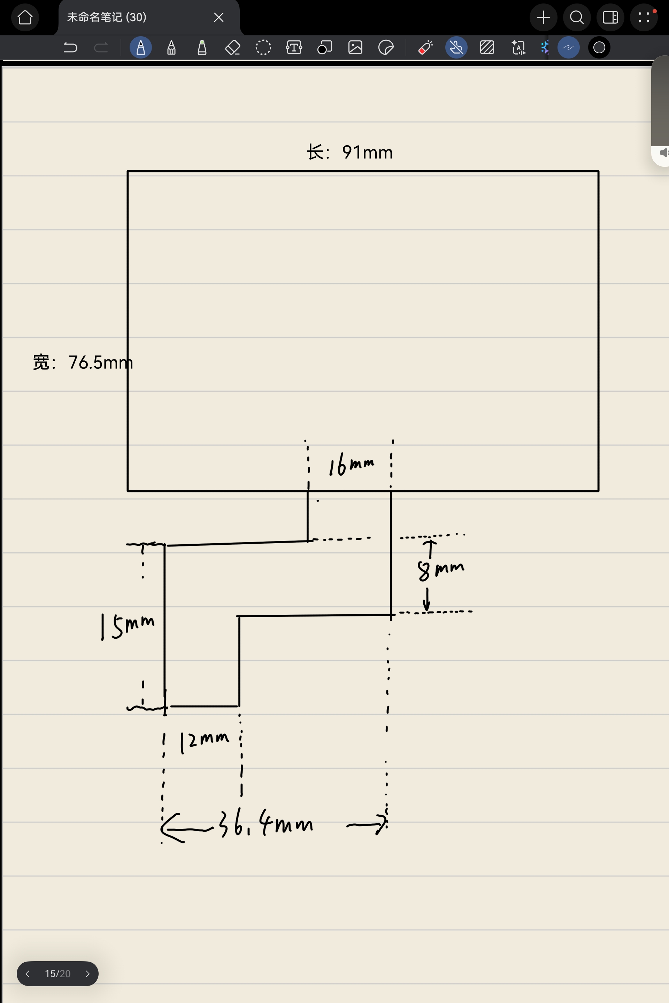
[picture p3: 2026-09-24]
3dmodels/显示器和排线.jpg

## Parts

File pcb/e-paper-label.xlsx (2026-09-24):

No. | Quantity | Comment | Designator | Footprint | Value | Manufacturer Part | Manufacturer | Supplier Part | Supplier
1 | 1 | RFANT3216120A5T | ANT1 | FILTER-SMD_1206-2P-L3.2-W1.6-L |  | RFANT3216120A5T | Walsin(华新科) | C127629 | LCSC
2 | 2 | 100nF | C1,C25 | C0603 | 100nF | GRM155R71H104KE14D | muRata(村田) | C77020 | LCSC
3 | 4 | 1uF | C5,C51,C53,C54 | C0603 | 1uF | CL05A105KA5NQNC | SAMSUNG(三星) | C52923 | LCSC
4 | 9 | 1uF | C6,C7,C9,C11,C12,C13,C15,C16,C67 | C0603 | 1uF | CL05A105KL5NRNC | SAMSUNG(三星) | C307413 | LCSC
5 | 1 | 1uF | C8 | C0603 | 1uF | GRM155R71H104KE14D | muRata(村田) |  | LCSC
6 | 2 | 10pF | C10,C47 | C0603 | 10pF | CL05A105KA5NQNC | SAMSUNG(三星) |  | LCSC
7 | 1 | 100nF | C14 | C0603 | 100nF | CL05A105KA5NQNC | SAMSUNG(三星) |  | LCSC
8 | 1 | 4.7uF | C26 | C0603 | 4.7uF | CL05A475KP5NRNC | SAMSUNG(三星) | C368809 | LCSC
9 | 6 | 100nF | C39,C41,C52,C55,C58,C62 | C0603 | 100nF
10 | 1 | 1uF | C40 | C0603 | 1uF
11 | 1 | 10uF | C46 | C0603 | 10uF | CL10A106MA8NRNC | SAMSUNG(三星) | C96446 | LCSC
12 | 1 | DNF | C48 | C0603 | DNF | CL05A105KA5NQNC | SAMSUNG(三星) |  | LCSC
13 | 2 | 2.2uF | C49,C50 | C0603 | 2.2uF | CL05A105KA5NQNC | SAMSUNG(三星) |  | LCSC
14 | 1 | 4.7uF | C59 | C0603 | 4.7uF
15 | 2 | DNP | C60,C63 | C0603 | DNP
16 | 1 | DNF | C64 | C0603 | DNF
17 | 1 | AFC12-S02DCC-00 | CN1 | CONN-SMD_AFC12-S02DCC-00 |  | AFC12-S02DCC-00 | JS(钜硕电子) | C395328 | LCSC
18 | 1 | B5819W | D4 | SOD-123_L2.8-W1.8-LS3.7-RD-1 |  | B5819W | JSMSEMI(杰盛微) | C917036 | LCSC
19 | 4 | MBR0530 | D7,D8,D9,D10 | SOD-123_L2.7-W1.6-LS3.6-RD |  | MBR0530 | R+O(宏嘉诚) | C55068180 | LCSC
20 | 1 | HC-FPC-05-09-24RLTAG | FPC1 | FPC-SMD_X05A26H24G |  | HC-FPC-05-09-24RLTAG | HCTL(华灿天禄) | C5213757 | LCSC
21 | 1 | 6.8nH | L1 | L0603 | 6.8nH | MLZ1005M2R2WT000 | TDK |  | LCSC
22 | 1 | 68uH | L2 | IND-SMD_L3.0-W3.0_ABG03A | 68uH | YNR3012-680M | YJYCOIN(益嘉源) | C497561 | LCSC
23 | 4 | NCD0603G1 | LED1,LED4,LED5,LED7 | LED0603-RD |  | NCD0603G1 | 国星光电 | C84267 | LCSC
24 | 1 | LED_0402-R | LED2 | LED_0603
25 | 1 | XL-1608UGC-04 | LED3 | LED0603-RD_GREEN |  | XL-1608UGC-04 | XINGLIGHT(成兴光) | C965804 | LCSC
26 | 1 | XL-1608UPC-06 | LED6 | LED0603-RD_PINK |  | XL-1608UPC-06 | XINGLIGHT(成兴光) | C2977076 | LCSC
27 | 2 | XL-1608UYC-06 | LED8,LED9 | LED0603-RD-YELLOW |  | XL-1608UYC-06 | XINGLIGHT(成兴光) | C965802 | LCSC
28 | 1 | XL-1608UOC-04 | LED11 | LED0603-RD_ORANGE |  | XL-1608UOC-04 | XINGLIGHT(成兴光) | C965801 | LCSC
29 | 1 | DMP2305U | Q1 | SOT-23-3_L2.9-W1.3-P0.95-LS2.4-BR |  | DMP2305U | TECH PUBLIC(台舟) | C2940630 | LCSC
30 | 1 | AO3401A | Q5 | SOT-23-3_L2.9-W1.3-P1.90-LS2.4-BR |  | AO3401A | HUASHUO(华朔) | C700954 | LCSC
31 | 2 | MMBT3906 | Q9,Q10 | SOT-23-3_L2.9-W1.3-P1.90-LS2.4-BR |  | MMBT3906 | R+O(宏嘉诚) | C7420354 | LCSC
32 | 1 | MMBT3904(RANGE:100-300) | Q11 | SOT-23-3_L2.9-W1.3-P1.90-LS2.4-BR |  | MMBT3904(RANGE:100-300) | CJ(江苏长电/长晶) | C20526 | LCSC
33 | 1 | 30K | R1 | R0603 | 30K | RC0402FR-0710KL | YAGEO(国巨) |  | LCSC
34 | 2 | 2kΩ | R2,R3 | R0603 | 2kΩ | 0402WGF2001TCE | UNI-ROYAL(厚声) | C4109 | LCSC
35 | 1 | 1kΩ | R4 | R0603 | 1kΩ | 0402WGF1002TCE | UNI-ROYAL(厚声) |  | LCSC
36 | 1 | 10kΩ | R5 | R0603 | 10kΩ | RC0402FR-0710KL | YAGEO(国巨) | C60490 | LCSC
37 | 1 | 0.47 | R6 | R0603 | 0.47 | 0402WGF4700TCE | UNI-ROYAL(厚声) |  | LCSC
38 | 2 | NC | R8,R54 | R0603 | NC
39 | 1 | 10K | R9 | R0603 | 10K | 0Ω_0402_±10% |  |  | LCSC
40 | 2 | 5.1K | R25,R26 | R0603 | 5.1K
41 | 1 | 10kΩ | R34 | R0603 | 10kΩ | 0402WGF1002TCE | UNI-ROYAL(厚声) | C25744 | LCSC
42 | 1 | 0 | R36 | R0603 | 0 | 0Ω_0402_±10% |  |  | LCSC
43 | 8 | 1K | R40,R41,R52,R53,R60,R72,R73,R76 | R0603 | 1K
44 | 2 | 4.7K | R42,R43 | R0603 | 4.7K
45 | 11 | 10K | R44,R47,R48,R55,R56,R57,R58,R59,R62,R65,R70 | R0603 | 10K
46 | 1 | 47K | R61 | R0603 | 47K
47 | 4 | 100K | R63,R66,R68,R69 | R0603 | 100K
48 | 2 | 2K | R71,R77 | R0603 | 2K
49 | 2 | 200 | R74,R75 | R0603 | 200
50 | 4 | M3螺丝 | SCREW2,SCREW3,SCREW4,SCREW5 | M3螺丝
51 | 2 | TS-1088-AR02016 | SW2,SW3 | SW-SMD_L3.9-W3.0-P4.45 |  | TS-1088-AR02016 | XUNPU(讯普) | C720477 | LCSC
52 | 1 | CH9140 | U1 | QFN-28_L4.0-W4.0-P0.40-BL-EP2.7 |  | CH9140 | WCH(南京沁恒) | C2887251 | LCSC
53 | 1 | STM32G070CBT6 | U2 | LQFP-48_L7.0-W7.0-P0.50-LS9.0-BL |  | STM32G070CBT6 | ST(意法半导体) | C529338 | LCSC
54 | 1 | TP4054 | U3 | TSOT-23-5_L2.9-W1.6-P0.95-LS2.8-BR |  | TP4054 | UMW(广东友台半导体) | C668215 | LCSC
55 | 1 | SSM3K09FU-VB | U6 | SC-70-3_L2.1-W1.3-P1.30-LS2.1-BR |  | SSM3K09FU-VB | VBsemi(微碧半导体) | C19188178 | LCSC
56 | 1 | CH340X | U9 | MSOP-10_L3.0-W3.0-P0.50-LS5.0-BL |  | CH340X | WCH(南京沁恒) | C3035748 | LCSC
57 | 1 | 13.56MHz | U13 | SOIC-8_L5.0-W4.0-P1.27-LS6.0-BL | 13.56MHz | ST25DV04K-IER6S3 | ST(意法半导体) | C155601 | LCSC
58 | 2 | XC6210B332MR | U14,U16 | TSOT-23-5_L2.9-W1.6-P0.95-LS2.8-BR |  | XC6210B332MR | TOREX(特瑞仕) | C424705 | LCSC
59 | 1 | AHT20 | U17 | SENSOR-SMD_L3.0-W3.0-P1.00-BR |  | AHT20 | 广州奥松 | C2757850 | LCSC
60 | 1 | 双塑单排排针5PIN2.54间距 | U18 | HDR-TH_5P-P2.54-V-M-A |  | 双塑单排排针5PIN2.54间距 |  | C9900029195 | LCSC
61 | 1 | 74HC595PW,118 | U19 | TSSOP-16_L5.0-W4.4-P0.65-LS6.4-BL |  | 74HC595PW,118 | Nexperia(安世) | C5948 | LCSC
62 | 1 | TYPE-C 16PIN 2MD(073) | USB1 | USB-C-SMD_TYPE-C-16PIN-2MD-073 |  | TYPE-C 16PIN 2MD(073) | SHOU HAN(首韩) | C2765186 | LCSC
63 | 1 | 32MHz | X1 | CRYSTAL-SMD_4P-L2.0-W1.6-BL | 32MHz | XL7EL89CKI-111YLC-32M | YXC(扬兴晶振) | C2965582 | LCSC

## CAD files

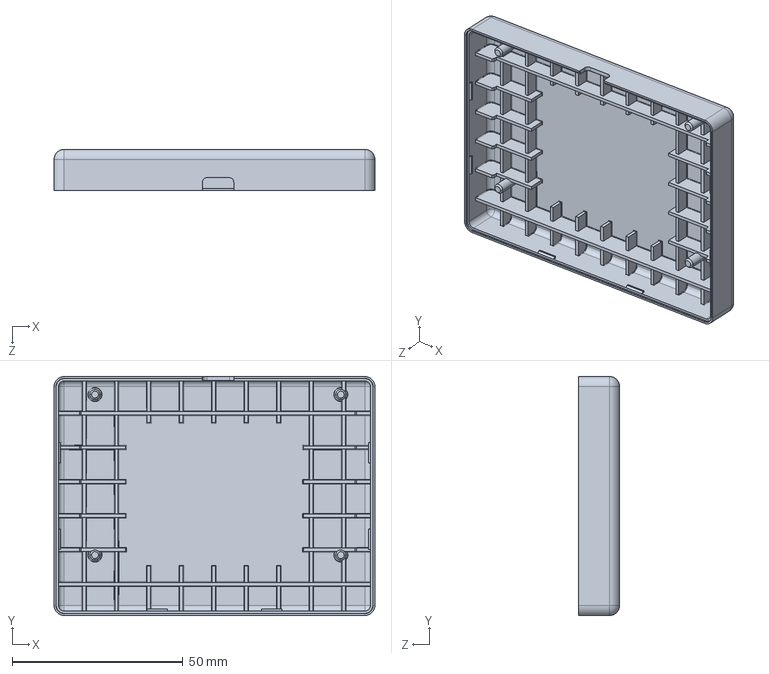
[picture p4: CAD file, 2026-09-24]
3dmodels/底座1.STEP
94.0 x 70.0 x 12.1 mm

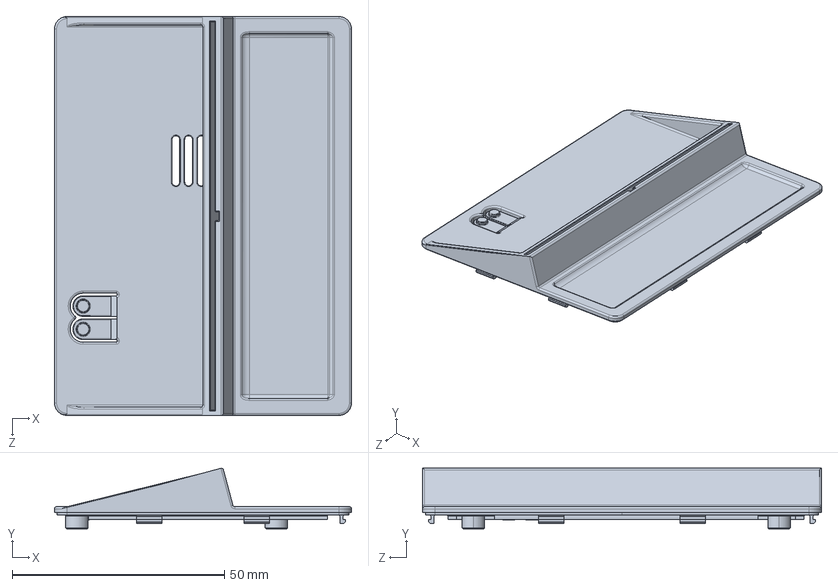
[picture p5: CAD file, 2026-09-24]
3dmodels/顶盖1.STEP
70.0 x 14.3 x 94.0 mm

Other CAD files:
3dmodels/Screen_FPC.blend

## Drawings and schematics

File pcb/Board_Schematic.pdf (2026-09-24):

NFC感应模块 | NFC供电控制

## 温湿度传感器

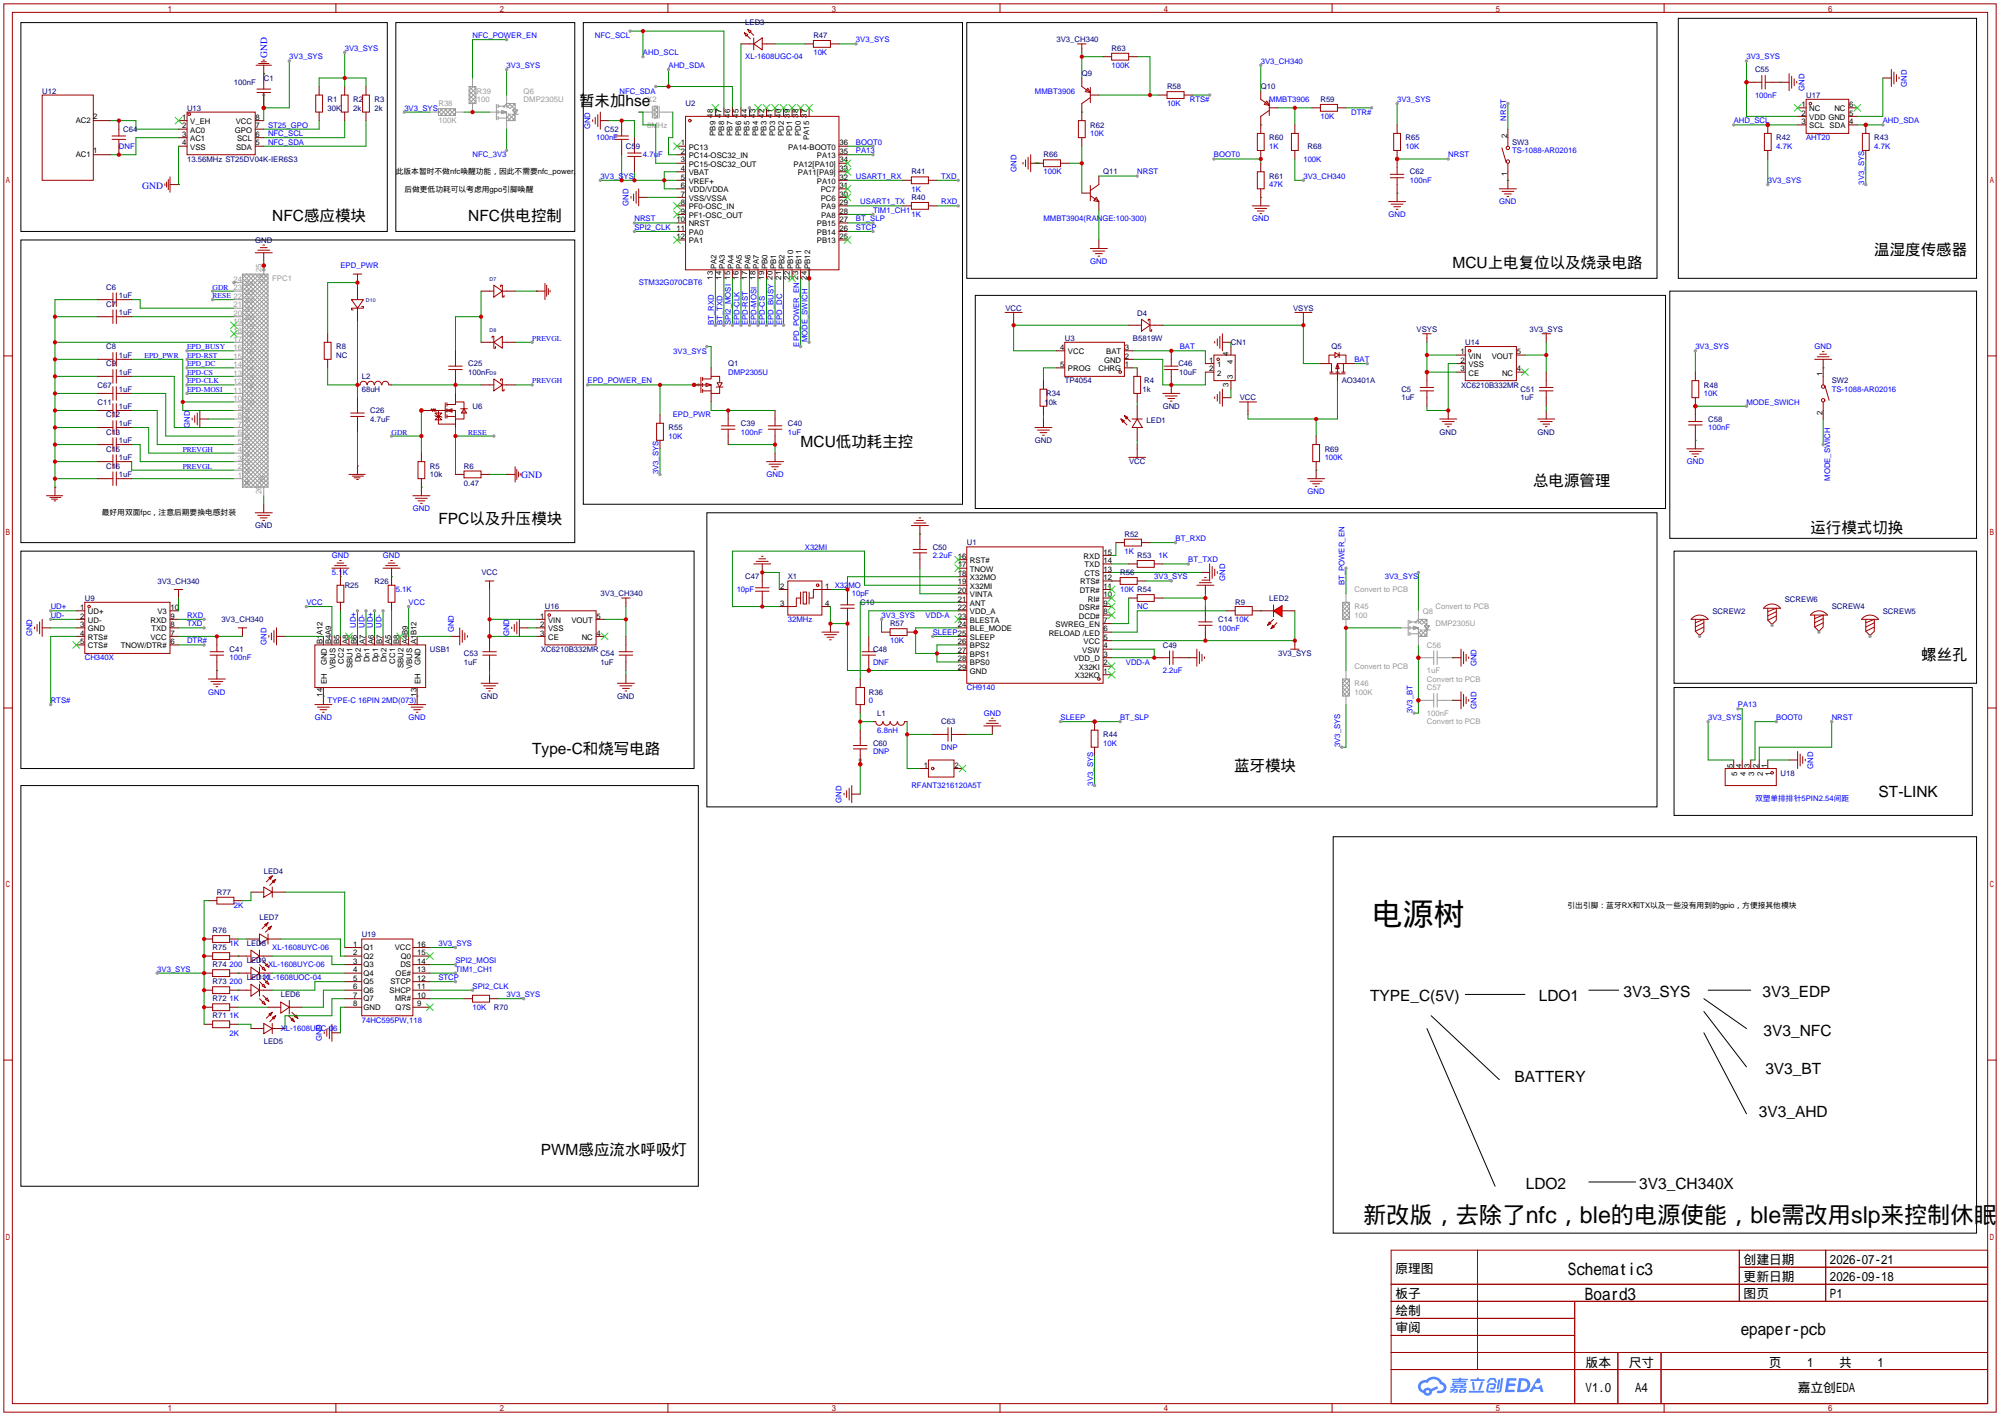
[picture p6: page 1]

RI# 10 DTR# 11 RTS# 12 CTS 13 TXD 14 RXD 15

GND A1B12 VBUS A4B9 SBU2 B8 CC1 A5 Dn2 B7 Dp1 A6 Dn1 A7 Dp2 B6 SBU1 A8 CC2 B5 VBUS B4A9 GND B1A12 EH 14 EH 13

MR# 10 SHCP 11 STCP 12 OE# 13 DS 14 Q0 15 VCC 16

新改版，去除了nfc，ble的电源使能，ble需改用slp来控制休眠

原理图 | Schematic3 | 创建日期 | 2026-07-21

更新日期 | 2026-09-18

板子 | Board3 | 图页 | P1
绘制 | | epaper-pcb
审阅

V1.0 | A4 | 嘉立创EDA

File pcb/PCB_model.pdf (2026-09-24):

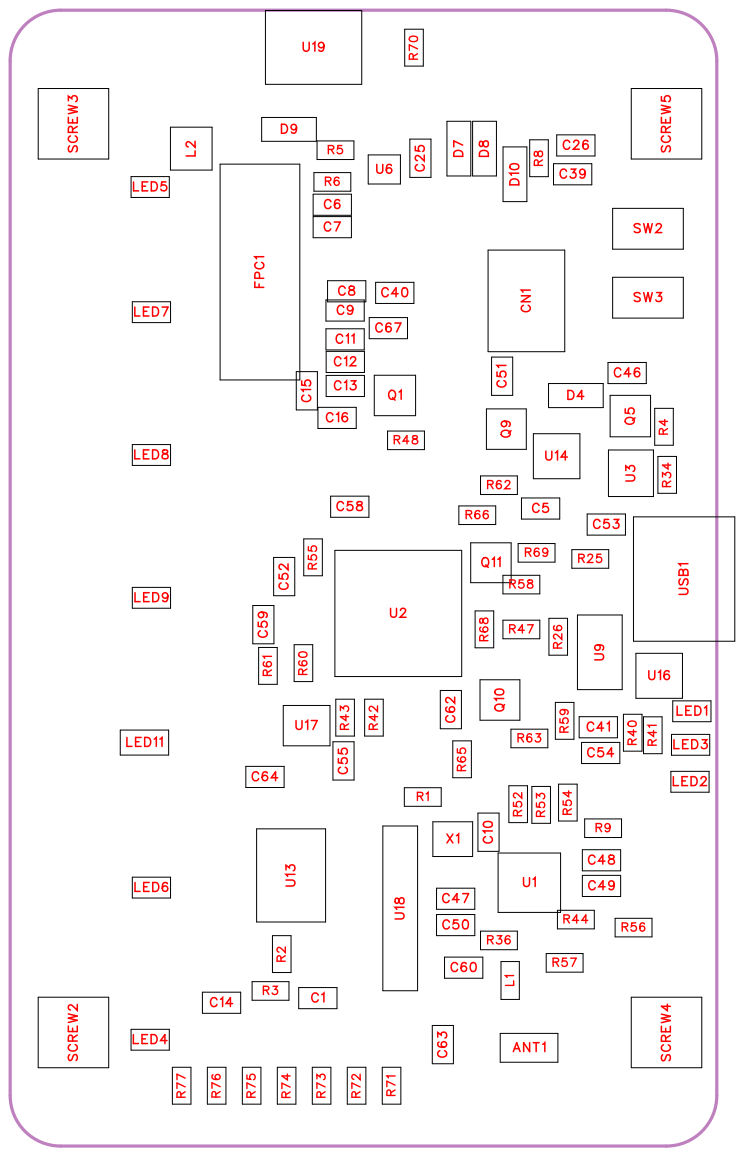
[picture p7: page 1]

LED5 | R6 | U6 | C39

No. | Quantity | Comment | Designator | Footprint | Value | Manufacturer Part | Manufacturer | Supplier Part | Supplier
1 | 1 | RFANT3216 120A5T | ANT1 | FILTER-SMD _1206-2P-L3. 2-W1.6-L | | RFANT3216 120A5T | Walsin(华新 科) | C127629 | LCSC
2 | 2 | 100nF | C1,C25 | C0603 | 100nF | GRM155R71 H104KE14D | muRata(村田 ) | C77020 | LCSC
3 | 4 | 1uF | C5,C51,C53,C54 | C0603 | 1uF | CL05A105KA 5NQNC | SAMSUNG( 三星) | C52923 | LCSC
4 | 9 | 1uF | C6,C7,C9,C11,C12,C13,C1 5,C16,C67 | C0603 | 1uF | CL05A105KL 5NRNC | SAMSUNG( 三星) | C307413 | LCSC
5 | 1 | 1uF | C8 | C0603 | 1uF | GRM155R71 H104KE14D | muRata(村田 ) | | LCSC
6 | 2 | 10pF | C10,C47 | C0603 | 10pF | CL05A105KA 5NQNC | SAMSUNG( 三星) | | LCSC
7 | 1 | 100nF | C14 | C0603 | 100nF | CL05A105KA 5NQNC | SAMSUNG( 三星) | | LCSC
8 | 1 | 4.7uF | C26 | C0603 | 4.7uF | CL05A475KP 5NRNC | SAMSUNG( 三星) | C368809 | LCSC
9 | 6 | 100nF | C39,C41,C52,C55,C58,C62 | C0603 | 100nF
10 | 1 | 1uF | C40 | C0603 | 1uF
11 | 1 | 10uF | C46 | C0603 | 10uF | CL10A106M A8NRNC | SAMSUNG( 三星) | C96446 | LCSC
12 | 1 | DNF | C48 | C0603 | DNF | CL05A105KA 5NQNC | SAMSUNG( 三星) | | LCSC
13 | 2 | 2.2uF | C49,C50 | C0603 | 2.2uF | CL05A105KA 5NQNC | SAMSUNG( 三星) | | LCSC
14 | 1 | 4.7uF | C59 | C0603 | 4.7uF
15 | 2 | DNP | C60,C63 | C0603 | DNP
16 | 1 | DNF | C64 | C0603 | DNF
17 | 1 | AFC12-S02D CC-00 | CN1 | CONN-SMD_ AFC12-S02D CC-00 | | AFC12-S02D CC-00 | JS(钜硕电子) | C395328 | LCSC
18 | 1 | B5819W | D4 | SOD-123_L2 .8-W1.8-LS3. 7-RD-1 | | B5819W | JSMSEMI(杰 盛微) | C917036 | LCSC
19 | 4 | MBR0530 | D7,D8,D9,D10 | SOD-123_L2 .7-W1.6-LS3. 6-RD | | MBR0530 | R+O(宏嘉诚) | C55068180 | LCSC
20 | 1 | HC-FPC-05-09-24RLTAG | FPC1 | FPC-SMD_X 05A26H24G | | HC-FPC-05-09-24RLTAG | HCTL(华灿天 禄) | C5213757 | LCSC
21 | 1 | 6.8nH | L1 | L0603 | 6.8nH | MLZ1005M2 R2WT000 | TDK | | LCSC
22 | 1 | 68uH | L2 | IND-SMD_L3 .0-W3.0_AB G03A | 68uH | YNR3012-68 0M | YJYCOIN(益 嘉源) | C497561 | LCSC
23 | 4 | NCD0603G1 | LED1,LED4,LED5,LED7 | LED0603-RD | | NCD0603G1 | 国星光电 | C84267 | LCSC
24 | 1 | LED_0402-R | LED2 | LED_0603

25 | 1 | XL-1608UGC -04 | LED3 | LED0603-RD _GREEN | | XL-1608UGC -04 | XINGLIGHT( 成兴光 ) | C965804 | LCSC
26 | 1 | XL-1608UPC -06 | LED6 | LED0603-RD _PINK | | XL-1608UPC -06 | XINGLIGHT( ) 成兴光 | C2977076 | LCSC
27 | 2 | XL-1608UYC -06 | LED8,LED9 | LED0603-RD -YELLOW | | XL-1608UYC -06 | XINGLIGHT( ) 成兴光 | C965802 | LCSC
28 | 1 | XL-1608UOC -04 | LED11 | LED0603-RD _ORANGE | | XL-1608UOC -04 | XINGLIGHT( 成兴光 ) | C965801 | LCSC
29 | 1 | DMP2305U | Q1 | SOT-23-3_L2 .9-W1.3-P0.9 5-LS2.4-BR | | DMP2305U | TECH PUBLI C(台舟 ) | C2940630 | LCSC
30 | 1 | AO3401A | Q5 | SOT-23-3_L2 .9-W1.3-P1.9 0-LS2.4-BR | | AO3401A | HUASHUO( 华朔 ) | C700954 | LCSC
31 | 2 | MMBT3906 | Q9,Q10 | SOT-23-3_L2 .9-W1.3-P1.9 0-LS2.4-BR | | MMBT3906 | R+O(宏嘉诚 ) | C7420354 | LCSC
32 | 1 | MMBT3904( RANGE:100-300) | Q11 | SOT-23-3_L2 .9-W1.3-P1.9 0-LS2.4-BR | | MMBT3904( RANGE:100-300) | CJ(江苏长电 / 长晶 ) | C20526 | LCSC
33 | 1 | 30K | R1 | R0603 | 30K | RC0402FR-0 710KL | YAGEO(国巨 ) | | LCSC
34 | 2 | 2k | R2,R3 | R0603 | 2k | 0402WGF20 01TCE | UNI-ROYAL( ) 厚声 | C4109 | LCSC
35 | 1 | 1k | R4 | R0603 | 1k | 0402WGF10 02TCE | UNI-ROYAL( ) 厚声 | | LCSC
36 | 1 | 10k | R5 | R0603 | 10k | RC0402FR-0 710KL | YAGEO(国巨 ) | C60490 | LCSC
37 | 1 | 0.47 | R6 | R0603 | 0.47 | 0402WGF47 00TCE | UNI-ROYAL( 厚声 ) | | LCSC
38 | 2 | NC | R8,R54 | R0603 | NC
39 | 1 | 10K | R9 | R0603 | 10K | 0 _0402_±1 0% | | | LCSC
40 | 2 | 5.1K | R25,R26 | R0603 | 5.1K
41 | 1 | 10k | R34 | R0603 | 10k | 0402WGF10 02TCE | UNI-ROYAL( 厚声 ) | C25744 | LCSC
42 | 1 | 0 | R36 | R0603 | 0 | 0 _0402_±1 0% | | | LCSC
43 | 8 | 1K | R40,R41,R52,R53,R60,R72 ,R73,R76 | R0603 | 1K
44 | 2 | 4.7K | R42,R43 | R0603 | 4.7K
45 | 11 | 10K | R44,R47,R48,R55,R56,R57 ,R58,R59,R62,R65,R70 | R0603 | 10K
46 | 1 | 47K | R61 | R0603 | 47K
47 | 4 | 100K | R63,R66,R68,R69 | R0603 | 100K
48 | 2 | 2K | R71,R77 | R0603 | 2K
49 | 2 | 200 | R74,R75 | R0603 | 200
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

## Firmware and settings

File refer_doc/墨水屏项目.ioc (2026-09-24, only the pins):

Mcu.UserName=STM32G070CBTx
PA0.GPIO_Label=SPI2_CLK
PA0.Signal=SPI2_SCK
PA10.GPIO_Label=CH340_TXD
PA10.Signal=USART1_RX
PA2.GPIO_Label=BT_RXD
PA2.Signal=USART2_TX
PA3.GPIO_Label=BT_TXD
PA3.Signal=USART2_RX
PA4.GPIO_Label=SPI2_MOSI
PA4.Signal=SPI2_MOSI
PA5.GPIO_Label=EPD-CLK
PA5.Signal=SPI1_SCK
PA6.GPIO_Label=EPD_RST
PA6.Signal=GPIO_Output
PA7.GPIO_Label=EPD-MOSI
PA7.Signal=SPI1_MOSI
PA8.GPIO_Label=LED_OE
PA8.Signal=GPIO_Output
PA9.GPIO_Label=CH340_RXD
PA9.Signal=USART1_TX
PB0.GPIO_Label=EPD-CS
PB0.Signal=GPIO_Output
PB1.GPIO_Label=EPD_BUSY
PB1.Signal=GPIO_Input
PB11.GPIO_Label=EPD_POWER_EN
PB11.Signal=GPIO_Output
PB12.GPIO_Label=MODE_SWICH
PB12.Signal=GPIO_Input
PB14.GPIO_Label=LED_STCP
PB14.Signal=GPIO_Output
PB15.GPIO_Label=BT_SLP
PB15.Signal=GPIO_Output
PB2.GPIO_Label=EPD_DC
PB2.Signal=GPIO_Output
PB7.GPIO_Label=NFC_SDA/AHD_SDA
PB7.Signal=I2C1_SDA
PB8.GPIO_Label=NFC_SCL/AHD_SCL
PB8.Signal=I2C1_SCL

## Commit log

2026-09-24 add submodule&pcb&3dmodels
    [Screen_FPC.blend, e-paper-label.xlsx, 底座1.STEP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]
2026-09-24 Update README.md
    Removed outdated information regarding Android Studio and Windows client project dependencies. Updated the section on current documentation scope to clarify the status of early development documents.
2026-09-24 制板文件&原理图
